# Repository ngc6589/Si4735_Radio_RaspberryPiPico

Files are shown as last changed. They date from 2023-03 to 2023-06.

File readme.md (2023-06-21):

# Si4735ラジオ概要

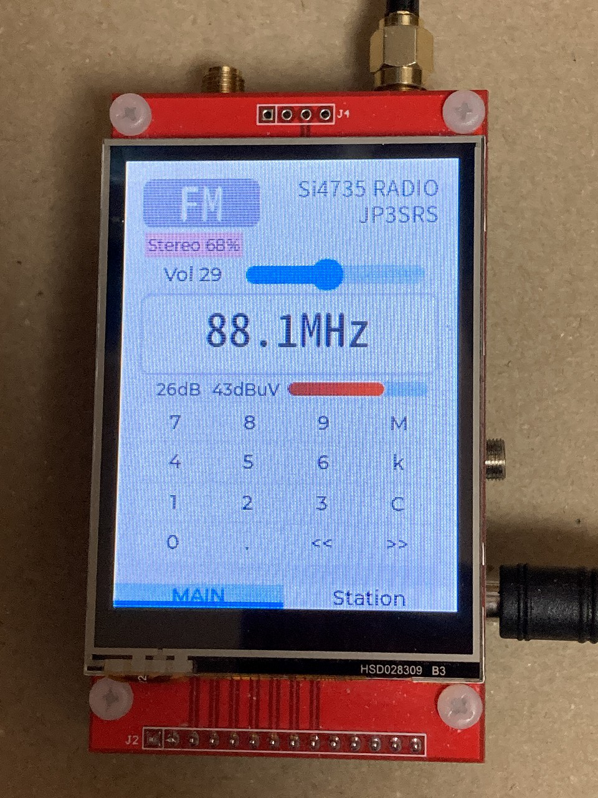
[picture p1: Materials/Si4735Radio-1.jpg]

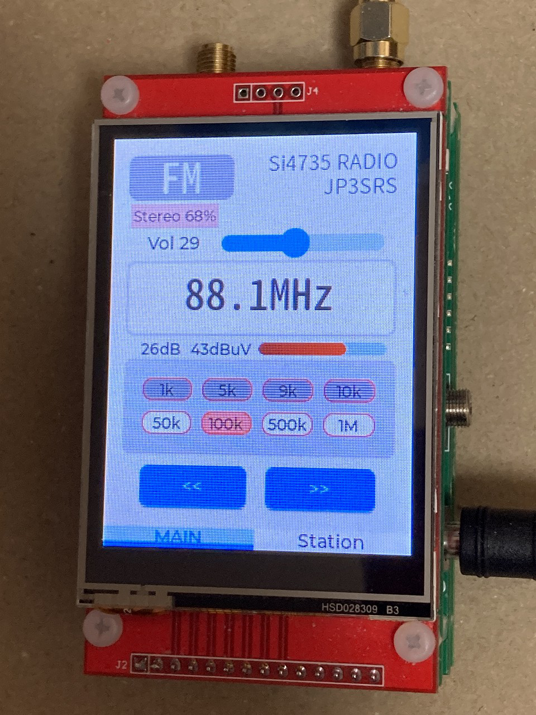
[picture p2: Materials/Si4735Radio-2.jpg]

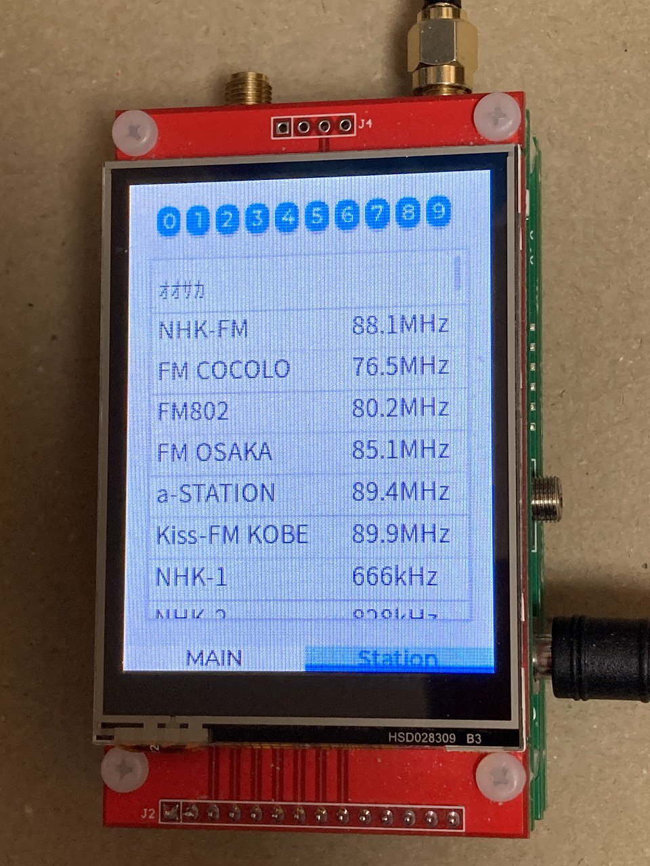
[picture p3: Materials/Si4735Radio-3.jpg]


Raspberry Pi Pico と ILI9341 タッチ液晶を使用し、Si4735 DSP ラジオチップを動かすラジオを製作しました。写真のように周波数を入力してチューニングする画面、ステップ周波数のUP/DOWNチューニング、選局リストからチューニングのモードを備えています。
このラジオの Raspberry Pi Pico のファームウエアは micropython に lvgl グラフィックライブラリをバインドした lv_micropython というものを使用しています。この lv_micropython は https://github.com/lvgl/lv_micropython にて公開されています。これにフリーフォントなどを加えたカスタマイズ版のファームウエアを作成しています。
このファームウエアに micropython で記述したラジオアプリケーションを動かして上記機能を実現しました。

現在 MicroPython は 1.20 がリリースされましたが、lv_micropython はまだ 1.19 なので、当ラジオのファームウエアの MicroPython は 1.19 です。

## 資料

|フォルダ|用途|
|---|---|
|Application|Raspberry Pi Pico の Micro Python ローカルストレージに格納するファイルです|
|Doc|回路図の pdf と部品表のエクセルファイル|
|KiCad_RaspberryPiPico|Raspberry Pi Pico の KiCad ファイルです。ガーバーは pico-20230412 フォルダに入っています|
|KiCad_SP|マイクロスピーカーを着ける KiCad ファイルです。ガーバーは SP-20230412 フォルダに入っています|
|KiCad_Si4735|Si4735 の KiCad ファイルです。ガーバーは RD-20230412 フォルダに入っています。この基板は4層です。
|lv_micropython_Firmware|Raspberry Pi Pico の Flash に書き込む lv_micropython のファームウエアです。firmware.uf2 を書き込んで下さい。

KiCad ファイルはバージョンは 7.0.2 で作成しました。

## 制限事項

* 画面ハングアップ

Raspberry Pi Pico の RAMが 264kB なので画面にグラフィックスウイジェットをたくさん出すとハングアップします。特に選局リストは放送局分のオブジェクトを内部で作成するので、選局リストをいじくりまわしていると固まることが多いです。選局して放置している分には特にハングアップは発生しません。
画面が動かなくなった場合が液晶基板右上に白いタクトスイッチが付いてます。これは RESET スイッチです。これを押して再起動してください。

今後 lvgl や micropython の新バージョンがリリースされても改善の見込みはありません。

* 電源スイッチはありません
* 電源電圧は 5V です。 

Raspberry Pi Pico のUSB端子もしくはとDCジャックから給電します。同時挿しも問題ありません。DCジャックから給電する場合は 5V のスイッチング AC アダプタを使用してください。

トランス式 AC アダプタの場合は表示が 5V でも電源電圧が 5V 以上になっているため使用できません。ラジオのボードは壊れます。

* 放送受信状態は、ご使用になられる場所。アンテナなどの受信設備の違いなど。受信環境の変化要素が多いため一定の保証をすることは困難です。あらかじめご了承願います。

## 簡単な使用方法

### 周波数入力とステップチューニング切り替え

周波数入力選局とステップチューニング画面は、画面上の余白をロングタップすると切り替わります。

### 選局リスト表示

選局リストチューニングは画面をスワイプもしくは画面下部の Station を押すと画面遷移します。戻るときは画面下部の MAIN を押すか画面スワイプで戻ります。

選局リスト画面上部に 0 ～ 9 のボタンがあります。ボタンをクリックすると micropython 内部ファイルシステムに格納してある [0-9].txt のファイルをリードして画面に表示します。

選局したい局の行をクリックするとその放送局にチューニングします。

### 周波数入力チューニング

周波数入力する時は「Ｃ」ボタンを押して、周波数表示が消えた状態で数字を入れて「ｋ」か「Ｍ」ボタンをクリックして選局します。
入力途中で「Ｃ」を押すと元の周波数表示に戻ります。
「＜＜」「＞＞」はシークチューニングです。シーク後放送局が見つかるとシーク動作は停止します。

### ステップチューニング

周波数表示の下に選択可能な周波数ステップボタンが表示されています。画面下部の「<<」「>>」1回クリックすると指定されたステップでチューニングします。長押しで連続ステップチューニング動作をします。

## AMモードゲインボリューム

LW/MW/SW 受信時は SMA コネクタの後に 3SK291 を使用した1石高周波増幅回路を搭載しています。増幅率は左側面アンテナコネクタ近くにボリウムを設けています。このボリウムを回して放送の聞こえ具合を調整してください。左に回し切ると1石増幅器は停止し、放送は聞こえなくなります。右に回し切るとお住まいの電波環境にもよりますが複数の局が混信して聞こえることがあります。

## アンテナ端子について

正面から見て左が LW/MW/SW 用で右が FM 放送用のアンテナ端子です。アンテナ端子の形状は SMA タイプです。

## I2S 出力端子について

2023年6月21日以前に購入された方は、I2S 出力ピンヘッダ横のダンピング抵抗 R1, R2, R3 を 100Ωに変えていただくことでビットクロックなどの波形が安定します。

|端子名|備考|
|-|-|
|BCLK|ビットクロック|
|DATA|データ|
|LRCK|LRクロック|
|GND|グランド|
|NC|未接続|
|VCC|5V出力 3.3vではありません|

I2S 出力するときは、プログラムのラジオチップ初期化のコマンドを I2S 出力対応にする必要があります。

```
# Generate 48k I2S clock
# uncomment I2S OUTPUT
# @rp2.asm_pio(
#     sideset_init=(rp2.PIO.OUT_HIGH, rp2.PIO.OUT_HIGH)
# )
# def gen48k():
#     set(x, 30)       .side(0b00) [1]
#     nop()            .side(0b01) [1]
#     label("L01")
#     nop()            .side(0b00) [1]
#     jmp(x_dec, "L01").side(0b01) [1]
#     set(x, 30)       .side(0b10) [1]
#     nop()            .side(0b11) [1]
#     label("R01")
#     nop()            .side(0b10) [1]
#     jmp(x_dec, "R01").side(0b11) [1]
# 
# sm0 = rp2.StateMachine(
#     0,
#     gen48k,
#     freq=12_288_000,
#     sideset_base=machine.Pin(4)
# )
# sm0.active(1)
```

のコメントを外します。
また、

```
    def FMPOWER_UP(self):
        self.i2c.writeto(self.addr, bytes([0x01, 0x00, 0x05]))  # analog Out
#         self.i2c.writeto(self.addr, bytes([0x01, 0x00, 0xB0]))   # I2S
        self.waitCTS()
        time.sleep(0.5)
        self.setProperty(bytes([0xFF, 0x00, 0x00, 0x00]))          # Turn off Debug Mode
#         self.setProperty(bytes([0x01, 0x04, 0xBB, 0x80]))        # I2s sample rate
```
```
    def AMPOWER_UP(self):
        self.i2c.writeto(self.addr, bytes([0x01, 0x01, 0x05])) # analog out
#         self.i2c.writeto(self.addr, bytes([0x01, 0x01, 0xB0]))  # I2S
        self.waitCTS()
        time.sleep(0.5)
        self.setProperty(bytes([0xFF, 0x00, 0x00, 0x00]))         # Turn off Debug Mode
#         self.setProperty(bytes([0x01, 0x04, 0xBB, 0x80]))       # I2S sample rate
```
の # analog out の行をコメントアウトして i2s のコメントを外すと I2S 出力になります。

デフォルトは 16bit/48k になります。

# プログラム更新

## thonny IDE
今回、ラジオのアプリケーション作成には 
Thonny Python IDE for beginners

https://thonny.org/

で、公開されている IDE を使用しています。
プログラムの修正などしてみる場合はこれをインストールして Si4735Radio の USB 接続すれば lv_micropython の REPL が使えるようになります。

ローカルのファイルを lv_micropython のファイルシステムにコピーしたりその逆も可。ファイルの修正も可能です。

## ファームウエア更新

液晶基板上側両再度に白いタクトスイッチが左右2個付いています。右がリセット・左がBOOTです。

「左BOOT」「右RESET」 両方押す

「右RESET」 離す

「左BOOT」 離す

この後 Raspberry Pi Pico は USB メモリモードになってホスト側PCのファイルに RPI PICO のドライブが使えるようになります。ここに .uf2 ファイルのドラッグ・ドロップ(コピーペースト)すればファームウエアの更新が可能です。

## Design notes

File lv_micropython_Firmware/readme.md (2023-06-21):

|folder|Version |
|---|--- |
|v1.19.1-678-ga71d593c2|lv_MicroPython 1.19.1 |
|v1.20.0-698-g3f25a765d|lv_microPython 1.20.0 |

-gハッシュ番号 は git の短いハッシュ番号です。当ラジオの Raspberry Pi Pico Firmware は、表にあるハッシュ番号がチェックアウトされた状態でビルドされています。

Raspberry Pi Pico の Boot ボタンを押した状態で PC に接続すると、PC に USB ストレージが追加されます。 firmware.uf2 をドラッグ＆ドロップで書き込みを行ってください。

lvgl MicroPython のリポジトリは以下のリンクです。
https://github.com/lvgl/lv_micropython

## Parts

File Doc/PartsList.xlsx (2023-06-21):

■Raspberry Pi Pico board
Reference(s) | Qty | Value | ITEM NUMBER | LINK
U1 | 1 | Raspberry Pi Pico | M-16132 | https://akizukidenshi.com/catalog/g/gM-16132/
LCD1 | 1 | MSP2807_ILI9341_2.8_SPI | M-16265 | https://akizukidenshi.com/catalog/g/gM-16265/
J1 | 1 | Pin Header 2x8 | C-00082 | https://akizukidenshi.com/catalog/g/gC-00082/
J2, J3 **1 | 2 | Pin Header 1x3 R/A
R1, R2 | 2 | 4.7k SMD 0603(1608) | 541-5454-1-ND | https://www.digikey.jp/ja/products/detail/vishay-dale/CRCW06034K70FKEAC/7925175
R3, R4, R5, R6 **3 | 4 | 100 SMD 0603(1608)
R7, R8, R9, R10, R11, R12, R13, R14, R15 | 9 | 51 SMD 0604(1608) | 541-51.0HCT-ND | https://www.digikey.jp/ja/products/detail/vishay-dale/CRCW060351R0FKEA/1174520
C1 **2 | 1 | 0.1uF SMD 0603(1608)
SW1, SW2 | 2 | TACTILE SWITCH | P-14890 | https://akizukidenshi.com/catalog/g/gP-14890/
 |  |  | 679-2400-ND | https://www.digikey.jp/ja/products/detail/apem-inc/MJTP1117/1795496
■Si4735 Board
Reference(s) | Qty | Value
U1 | 1 | Si4735-D60-GU | 336-2140-ND | https://www.digikey.jp/ja/products/detail/skyworks-solutions-inc/SI4735-D60-GU/2674322
U2 | 1 | TPA711DR | 296-1950-1-ND | https://www.digikey.jp/ja/products/detail/texas-instruments/TPA711DR/374589
U3 | 1 | TPA6111A2DR | 296-10846-1-ND | https://www.digikey.jp/ja/products/detail/texas-instruments/TPA6111A2DR/382220
Q1 | 1 | 3SK291 | I-10827 | https://akizukidenshi.com/catalog/g/gI-10827/
C1 | 1 | 100uF/25V SMD 6.3x7.7 | P-14452 | https://akizukidenshi.com/catalog/g/gP-14452/
C2, C12, C16 **2 | 3 | 0.1uF SMD 0603(1608)
C3 | 1 | 0.022uF X7R SMD 0603(1608) | 587-3503-1-ND | https://www.digikey.jp/ja/products/detail/taiyo-yuden/UMK107B7223KAHT/4157349
C4, C6 | 2 | 0.01uF SMD 0603(1608) | P-13387 | https://akizukidenshi.com/catalog/g/gP-13387/
C5 | 1 | 0.47uF X7R SMD 0603(1608) | 587-3170-1-ND | https://www.digikey.jp/ja/products/detail/taiyo-yuden/UMK107B7474KA-TR/3194963
C7 | 1 | 1000pF SMD 0603(1608) | P-02332 | https://akizukidenshi.com/catalog/g/gP-02332/
C10, C13 | 2 | 47uF SMD 1210(3225) | P-16078 | https://akizukidenshi.com/catalog/g/gP-16078/
C11, C15, C23 | 3 | 10p SMD 0603(1608) | P-05520 | https://akizukidenshi.com/catalog/g/gP-05520/
C14, C18, C20, C22 | 4 | 1uF X7R SMD 0603(1608) | P-14526 | https://akizukidenshi.com/catalog/g/gP-14526/
C17, C21 | 2 | 330uF/6.3V D=8mm PITCH=2.5mm | P-08374 | https://akizukidenshi.com/catalog/g/gP-08374/
C19 | 1 | 2.2uF SMD 0603(1608) | P-16077 | https://akizukidenshi.com/catalog/g/gP-16077/
D1 | 1 | 1N5819HW SOD-123 | 1N5819HW-FDICT-ND | https://www.digikey.jp/ja/products/detail/diodes-incorporated/1N5819HW-7-F/814970
D2, D3, D4, D5, D6, D7 | 6 | 1N4148W SOD-123 | I-07084 | https://akizukidenshi.com/catalog/g/gI-07084/
EMI1, EMI2, EMI3, EMI4, EMI5 | 5 | 4.7uF/6.3V FEEDTHRU 0603(1608) | 445-7080-1-ND | https://www.digikey.jp/ja/products/detail/tdk-corporation/YFF18PC0J475MT0H0N/2674882
J1 **1 | 1 | Pin Header 1x6 R/A
J2 | 1 | DC JACK MJ-179P | C-00077 | https://akizukidenshi.com/catalog/g/gC-00077/
J3 | 1 | Pin Socket 2x8 | C-02761 | https://akizukidenshi.com/catalog/g/gC-02761/
J4, J5 | 2 | AM/SW, FM | C-13195 | https://akizukidenshi.com/catalog/g/gC-13195/
J6 | 1 | MJ-352W-C | C-17359 | https://akizukidenshi.com/catalog/g/gC-17359/
L1 | 1 | FT37-77 (5977000201) 12T | 1934-1032-ND | https://www.digikey.jp/ja/products/detail/fair-rite-products-corp/5977000201/8593966
R1, R2, R3 **3 | 2 | 100 SMD 0603(1608)
R4 | 1 | 10 SMD 0603(1608) | 541-3952-1-ND | https://www.digikey.jp/ja/products/detail/vishay-dale/CRCW060310R0FKEAC/7928374
R5 | 1 | 22k SMD 0603(1608) | 541-4036-1-ND | https://www.digikey.jp/ja/products/detail/vishay-dale/CRCW060322K0FKEAC/7928458
R6 | 1 | 91k SMD 0603(1608) | 541-5595-1-ND | https://www.digikey.jp/ja/products/detail/vishay-dale/CRCW060391K0FKEAC/7924350
R7 | 1 | 39k SMD 0603(1608) | 541-5383-1-ND | https://www.digikey.jp/ja/products/detail/vishay-dale/CRCW060339K0FKEAC/7924024
R8, R16, R17 | 3 | 100k SMD 0603(1608) | 541-3950-1-ND | https://www.digikey.jp/ja/products/detail/vishay-dale/CRCW0603100KFKEAC/7928372
R9 | 1 | 47k SMD 0603(1608) | 541-4021-1-ND | https://www.digikey.jp/ja/products/detail/vishay-dale/CRCW060347K0FKEAC/7928443
R10, R14, R15, R19, R20 | 5 | 10k SMD 0603(1608) | 541-5136-1-ND | https://www.digikey.jp/ja/products/detail/vishay-dale/CRCW060310K0FKEAC/7924693
R11, R18 | 2 | 33k SMD 0603(1608) | 541-4041-1-ND | https://www.digikey.jp/ja/products/detail/vishay-dale/CRCW060333K0FKEAC/7928463
R12, R13 | 2 | 1k SMD 0603(1608) | 541-3949-1-ND | https://www.digikey.jp/ja/products/detail/vishay-dale/CRCW06031K00FKEAC/7928371
RV1 | 1 | 10k | P-14937 | https://akizukidenshi.com/catalog/g/gP-14937/
 |  |  | 312-1001F-10K | https://www.mouser.jp/ProductDetail/Alpha-Taiwan/RV100F-30-4K1B-B10K-B301?qs=e7hy8iQCIdxa76GAgn%252BWaA%3D%3D
RV2 | 1 | 10k TRIMMER | 3306W-103-ND | https://www.digikey.jp/ja/products/detail/bourns-inc/3306W-1-103/84781
LS1 **1 | 1 | 1x2 Pin Header
LS1 | 1 | MICRO SPEAKER | P-12495 | https://akizukidenshi.com/catalog/g/gP-12495/
■Si4735 Crystal Option
Reference(s) | Qty | Value
Y1 | 1 | 32.768kHz 3.2×1.5×0.80mm | P-07195 | https://akizukidenshi.com/catalog/g/gP-07195/
C8, C9 | 2 | 12pF C0G SMD 0603(1608) | 399-CBR06C120J5GACCT-ND | https://www.digikey.jp/ja/products/detail/kemet/CBR06C120J5GAC/3473711
■screw / other
Reference(s) | Qty | Value
M3 Screw 4mm | 8 | plastic screws M3 Length 4mm | N-0304 | https://www.hirosugi-net.co.jp/shop/g/g35880/
M3 Spacer 6mm | 8 | Duracon spacer M3 Length 6mm | BS-306E | https://www.hirosugi-net.co.jp/shop/g/g3761/
M3 Spacer 11mm | 4 | Duracon spacer M3 Length 11mm internal thread | AS-311 | https://www.hirosugi-net.co.jp/shop/g/g3724/
0.4 - 0.5mm UEW Wire | 1 | use L1 (FT37-77) 12T
**1
Pin Header 1x40 R/A | 1 | Pin Head 1x40 R/A | C-01627 | https://akizukidenshi.com/catalog/g/gC-01627/
**2
0.1uF (100n) | 3 | 0.1uF SMD 0603(1608) | P-16143 | https://akizukidenshi.com/catalog/g/gP-16143/
**3
100 ohm | 7 | 100 SMD 0603(1608) | 541-3951-1-ND | https://www.digikey.jp/ja/products/detail/vishay-dale/CRCW0603100RFKEAC/7928373

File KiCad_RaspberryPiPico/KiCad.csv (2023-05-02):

Source: | C:\Users\masahiro\OneDrive\make\_K-0025_Si4735Radio\KiCad_RaspberryPiPico\KiCad.kicad_sch
Date: | 2023/04/29 8:51:12
Tool: | Eeschema 7.0.2
Generator: | C:\Program Files\KiCad\7.0\bin\scripting\plugins/bom_csv_grouped_by_value.py
Component Count: | 27
Collated Components:
Item | Qty | Reference(s) | Value | LibPart | Footprint | Datasheet | DNP
1 | 1 | C1 | 0.1uF | Device:C | Capacitor_SMD:C_0603_1608Metric_Pad1.08x0.95mm_HandSolder | ~
2 | 4 | H1, H2, H3, H4 | MountingHole | Mechanical:MountingHole | MountingHole:MountingHole_3.2mm_M3 | ~
3 | 1 | J1 | Conn_02x08_Odd_Even | Connector_Generic:Conn_02x08_Odd_Even | Connector_PinHeader_2.54mm:PinHeader_2x08_P2.54mm_Vertical | ~
4 | 1 | J2 | DEBUG | Connector:Conn_01x03_Socket | Connector_PinSocket_2.54mm:PinSocket_1x03_P2.54mm_Horizontal | ~
5 | 1 | J3 | UART | Connector:Conn_01x03_Socket | Connector_PinSocket_2.54mm:PinSocket_1x03_P2.54mm_Horizontal | ~
6 | 1 | LCD1 | MSP2807_ILI9341_2.8_SPI | _localSymbol:MSP2807_ILI9341_2.8_SPI_wo_SD | Connector_PinSocket_2.54mm:PinSocket_1x14_P2.54mm_Vertical
7 | 2 | R1, R2 | 4.7k | Device:R | Resistor_SMD:R_0603_1608Metric_Pad0.98x0.95mm_HandSolder | ~
8 | 4 | R3, R4, R5, R6 | 100 | Device:R | Resistor_SMD:R_0603_1608Metric_Pad0.98x0.95mm_HandSolder | ~
9 | 9 | R7, R8, R9, R10, R11, R12, R13, R14, R15 | 51 | Device:R | Resistor_SMD:R_0603_1608Metric_Pad0.98x0.95mm_HandSolder | ~
10 | 1 | SW1 | RESET | _localSymbol:THBP07-043CW | _localFootprint:THBP07-043CW | http://www.apem.com/int/index.php?controller=attachment&id_attachment=1371
11 | 1 | SW2 | BOOT | _localSymbol:THBP07-043CW | _localFootprint:THBP07-043CW | http://www.apem.com/int/index.php?controller=attachment&id_attachment=1371
12 | 1 | U1 | Pico | _localSymbol:Pico | _localFootprint:RPi_Pico_SMD_TH

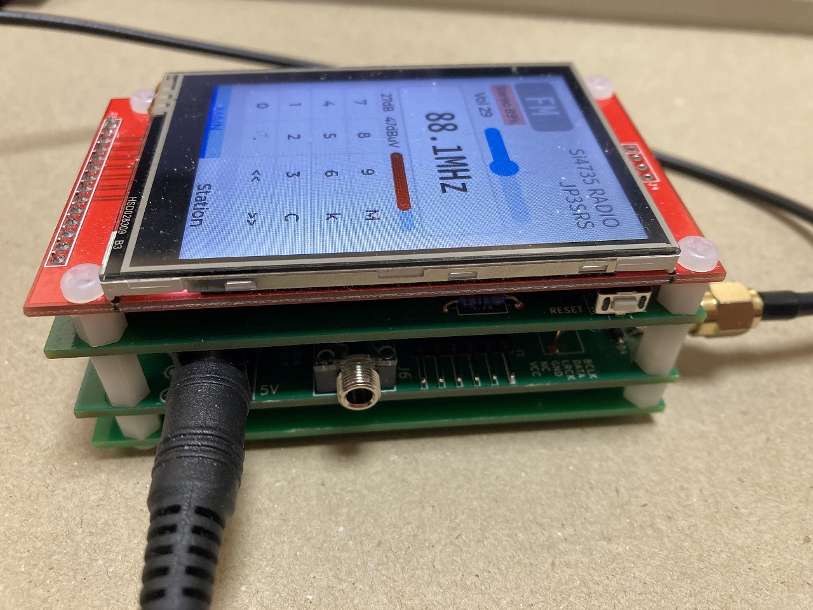
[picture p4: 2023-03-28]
Materials/Si4735Radio-5.jpg

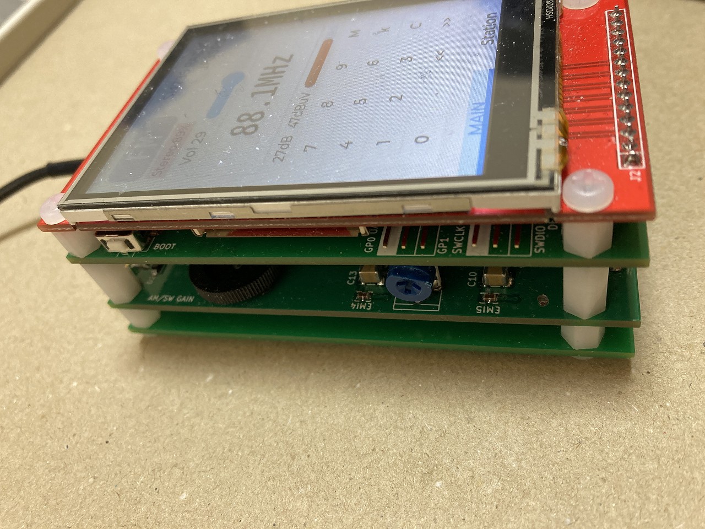
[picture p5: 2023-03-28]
Materials/Si4735Radio-4.jpg

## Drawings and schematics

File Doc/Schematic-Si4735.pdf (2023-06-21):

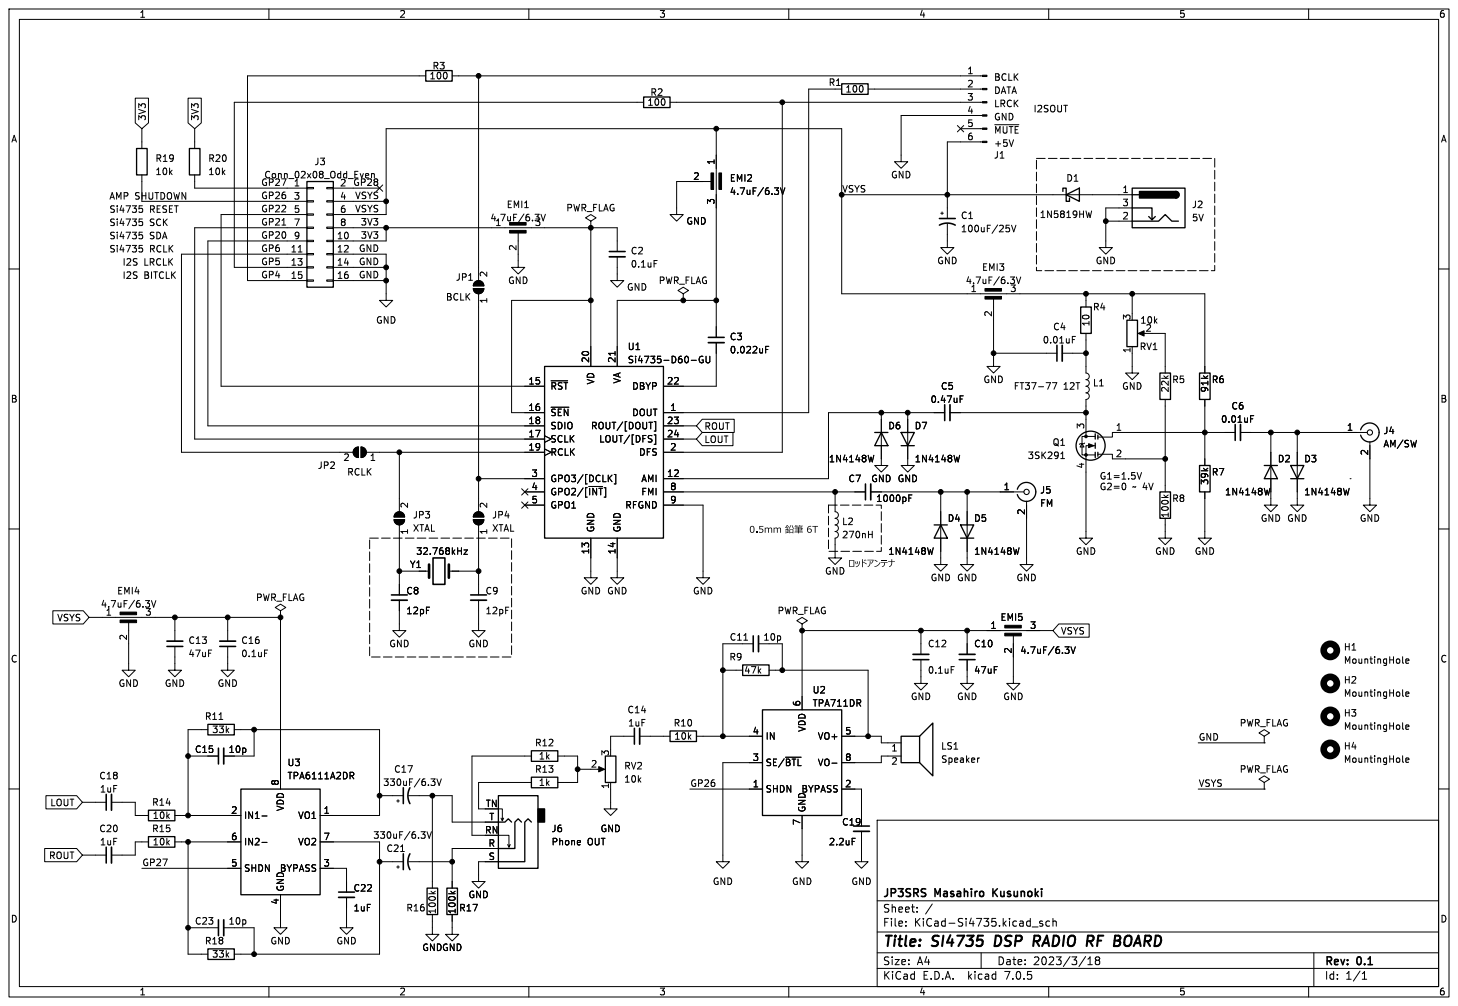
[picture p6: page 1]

1 2 JP4 XTAL DOUT 1 AMI 12 GND 13 GND 14

Id: 1/1 Title: SI4735 DSP RADIO RF BOARD

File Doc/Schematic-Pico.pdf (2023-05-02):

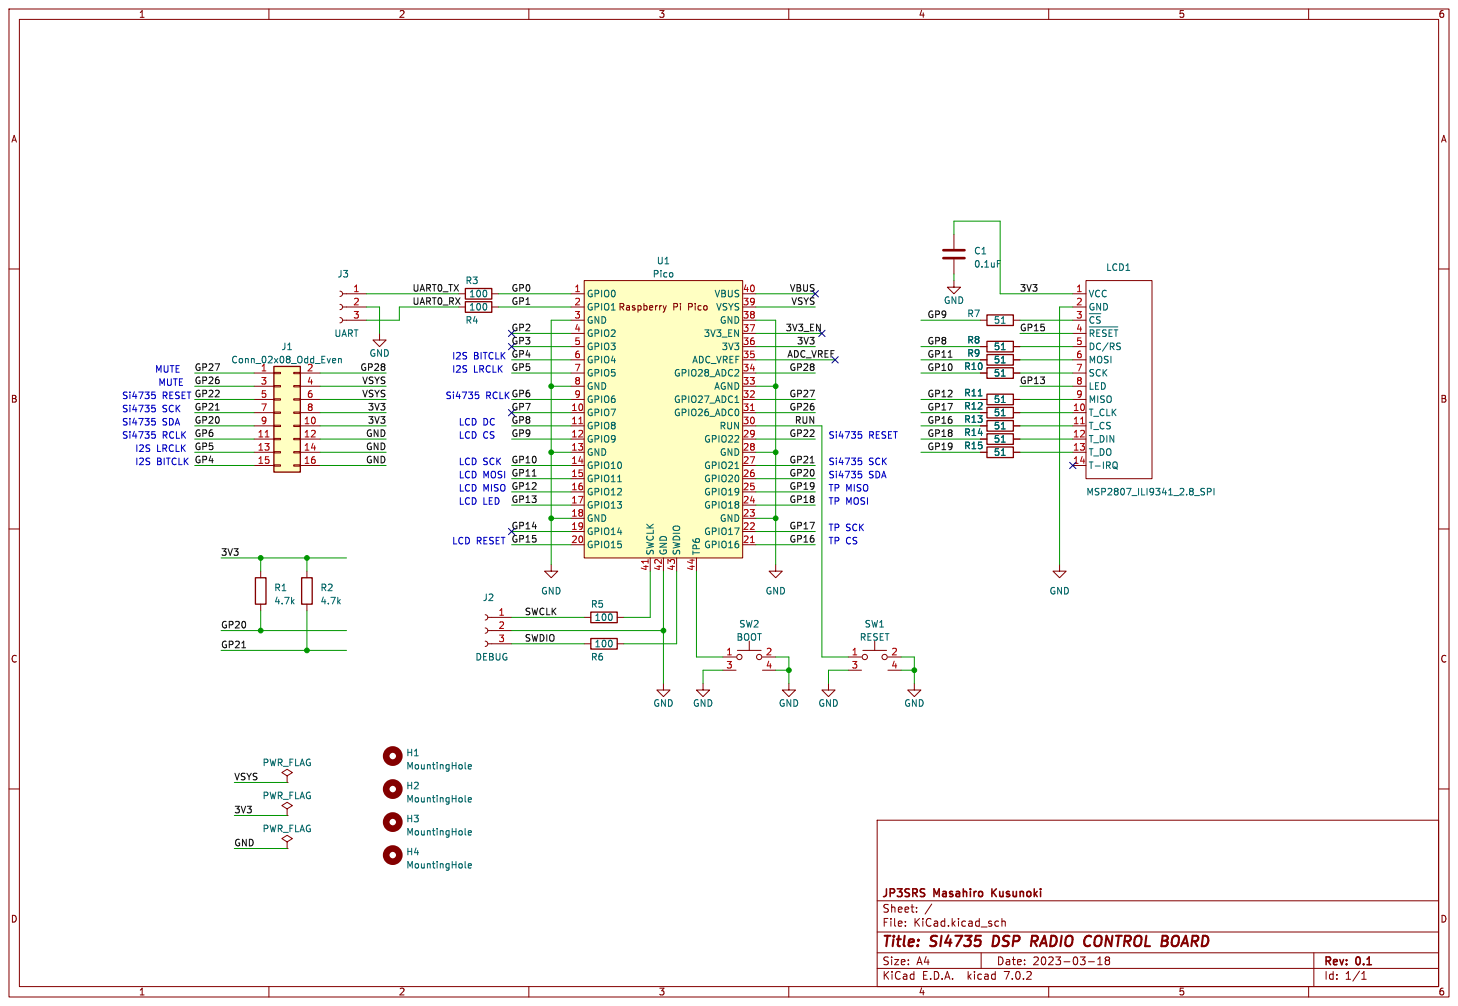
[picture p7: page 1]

LCD MOSI LCD SCK MUTE

Si4735 SCK
Si4735 SDA
TP MISO
TP MOSI TP SCK

H3 MountingHole H2 MountingHole H1 MountingHole H4 MountingHole R1

Id: 1/1 Title: SI4735 DSP RADIO CONTROL BOARD

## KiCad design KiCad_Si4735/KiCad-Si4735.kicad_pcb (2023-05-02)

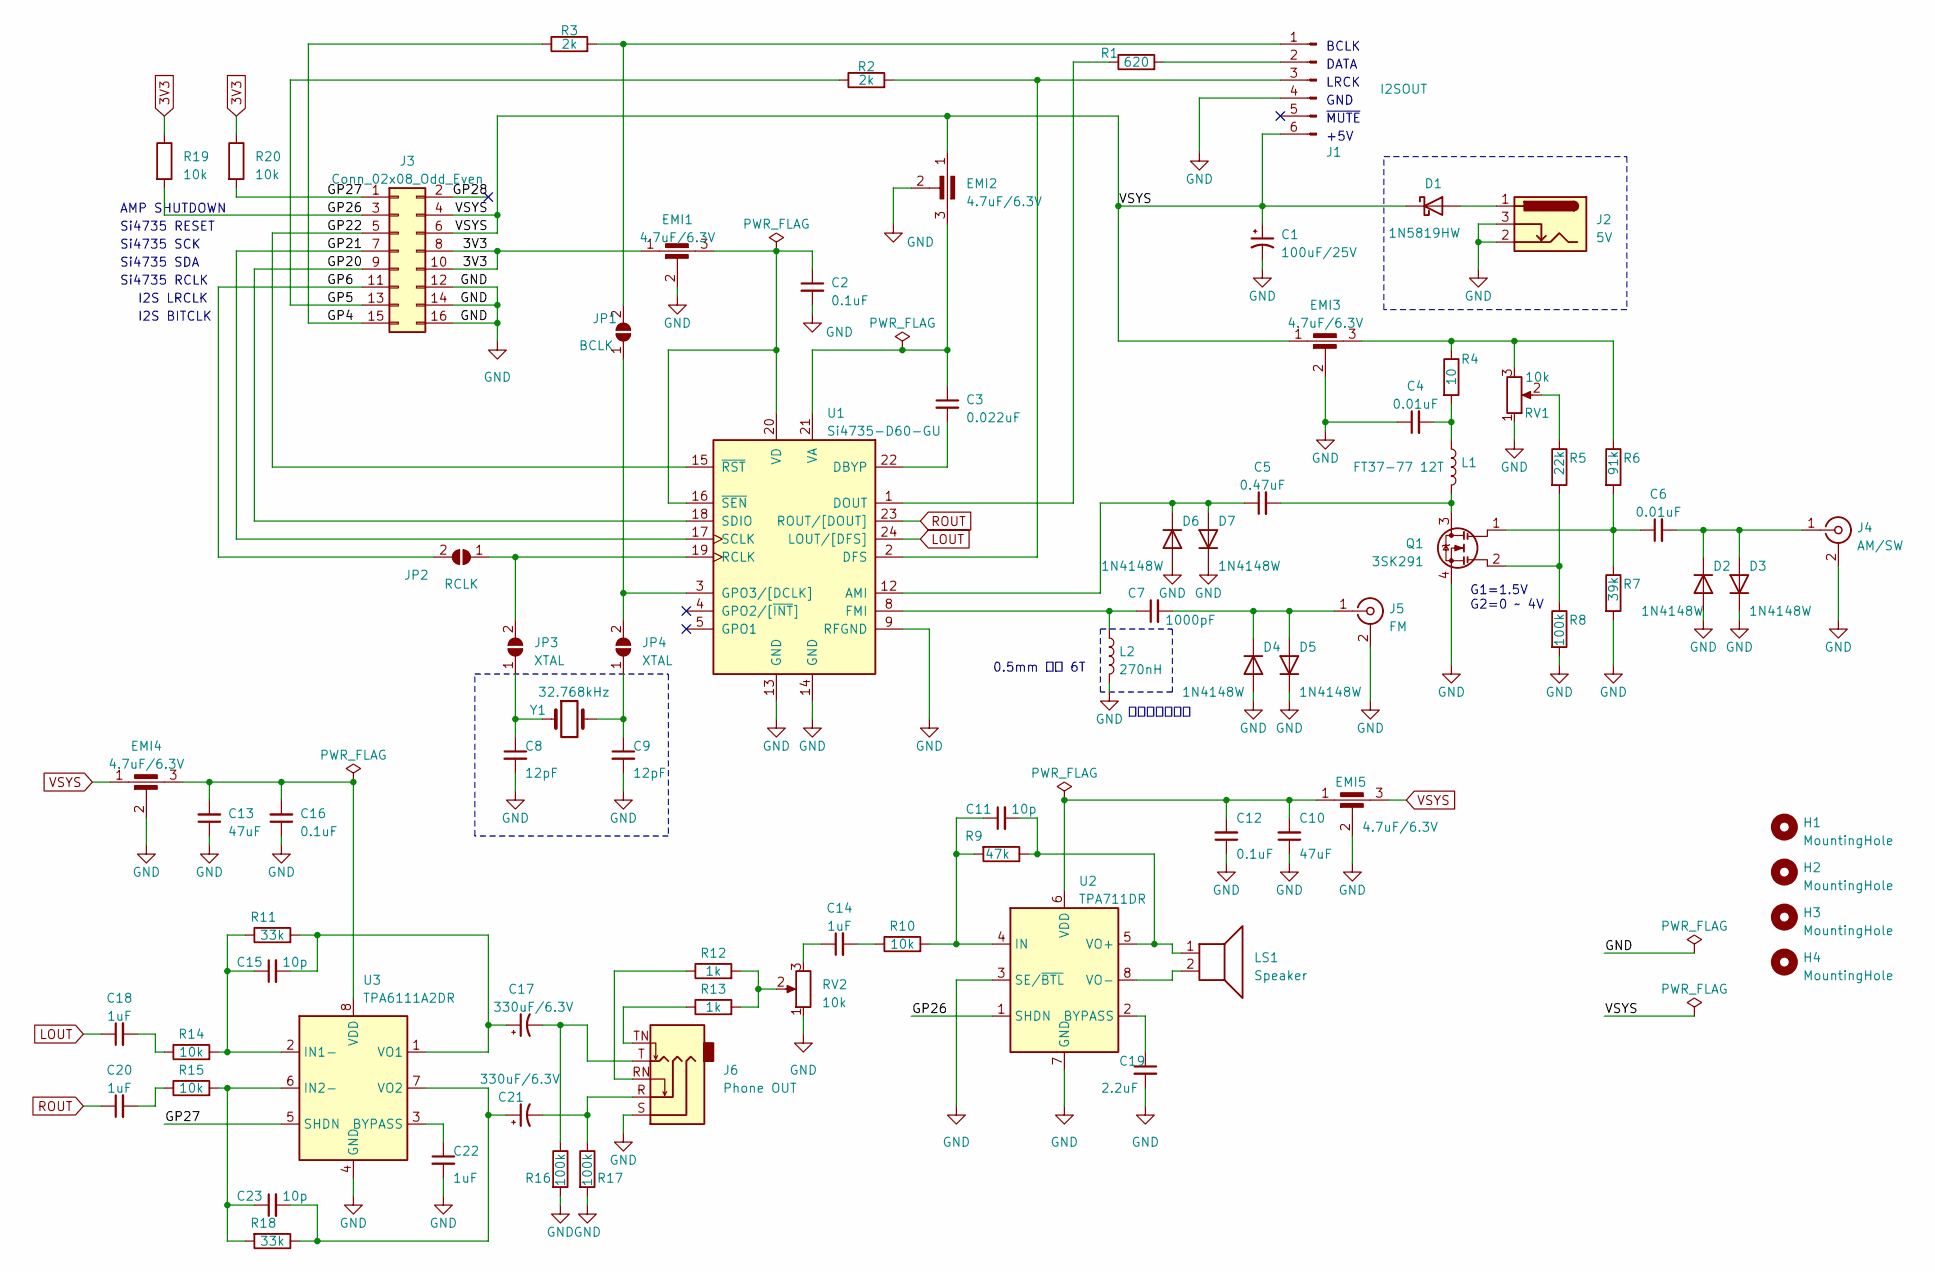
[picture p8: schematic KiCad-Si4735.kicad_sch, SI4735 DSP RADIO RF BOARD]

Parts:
C1: 100uF/25V; CP_Elec_6.3x7.7
C2, C12, C16: 0.1uF; C_0603_1608Metric_Pad1.08x0.95mm_HandSolder
C3: 0.022uF; C_0603_1608Metric_Pad1.08x0.95mm_HandSolder
C4, C6: 0.01uF; C_0603_1608Metric_Pad1.08x0.95mm_HandSolder
C5: 0.47uF; C_0603_1608Metric_Pad1.08x0.95mm_HandSolder
C7: 1000pF; C_0603_1608Metric_Pad1.08x0.95mm_HandSolder
C8, C9: 12pF; C_0603_1608Metric_Pad1.08x0.95mm_HandSolder
C10, C13: 47uF; C_1210_3225Metric_Pad1.33x2.70mm_HandSolder
C11, C15, C23: 10p; C_0603_1608Metric_Pad1.08x0.95mm_HandSolder
C14, C18, C20, C22: 1uF; C_0603_1608Metric_Pad1.08x0.95mm_HandSolder
C17, C21: 330uF/6.3V; CP_Radial_D8.0mm_P2.50mm
C19: 2.2uF; C_0603_1608Metric_Pad1.08x0.95mm_HandSolder
D1: 1N5819HW; D_SOD-123
D2, D3, D4, D5, D6, D7: 1N4148W; D_SOD-123
EMI1, EMI2, EMI3, EMI4, EMI5: 4.7uF/6.3V; YFF18PC
H1, H2, H3, H4: MountingHole; MountingHole_3.2mm_M3
J1: I2SOUT; PinHeader_1x06_P2.54mm_Horizontal
J2: 5V; MJ-179PH
J3: Conn_02x08_Odd_Even; PinHeader_2x08_P2.54mm_Vertical
J4: AM/SW; SMA-J-P-H-ST-EM1
J5: FM; SMA-J-P-H-ST-EM1
J6: Phone OUT; MJ-352W-0
JP1: BCLK; SolderJumper-2_P1.3mm_Open_Pad1.0x1.5mm
JP2: RCLK; SolderJumper-2_P1.3mm_Open_Pad1.0x1.5mm
JP3, JP4: XTAL; SolderJumper-2_P1.3mm_Open_Pad1.0x1.5mm
L1: FT37-77 12T; FT37
L2: 270nH; L2
LS1: Speaker; PinHeader_1x02_P2.54mm_Horizontal
Q1: 3SK291; SOT-143_Handsoldering
R1: 620; R_0603_1608Metric_Pad0.98x0.95mm_HandSolder
R2, R3: 2k; R_0603_1608Metric_Pad0.98x0.95mm_HandSolder
R4: 10; R_0603_1608Metric_Pad0.98x0.95mm_HandSolder
R5: 22k; R_0603_1608Metric_Pad0.98x0.95mm_HandSolder
R6: 91k; R_0603_1608Metric_Pad0.98x0.95mm_HandSolder
R7: 39k; R_0603_1608Metric_Pad0.98x0.95mm_HandSolder
R8, R16, R17: 100k; R_0603_1608Metric_Pad0.98x0.95mm_HandSolder
R9: 47k; R_0603_1608Metric_Pad0.98x0.95mm_HandSolder
R10, R14, R15, R19, R20: 10k; R_0603_1608Metric_Pad0.98x0.95mm_HandSolder
R11, R18: 33k; R_0603_1608Metric_Pad0.98x0.95mm_HandSolder
R12, R13: 1k; R_0603_1608Metric_Pad0.98x0.95mm_HandSolder
RV1: 10k; RV100F
RV2: 10k; 3306W
U1: Si4735-D60-GU; SSOP-24_3.9x8.7mm_P0.635mm
U2: TPA711DR; SO-8_3.9x4.9mm_P1.27mm
U3: TPA6111A2DR; SO-8_3.9x4.9mm_P1.27mm
Y1: 32.768kHz; FC-135

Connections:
3V3: EMI1.1, J3.8, J3.10, R19.1, R20.1
/GP4: J3.15, R3.1
/GP5: J3.13, R2.1
/GP6: J3.11, JP2.2 (B)
/GP20: J3.9, U1.18 (SDIO)
/GP21: J3.7, U1.17 (SCLK)
/GP22: J3.5, U1.15 (~RST)
/GP26: J3.3, R19.2, U2.1 (SHDN)
/GP27: J3.1, R20.2, U3.5 (SHDN)
/GP28: J3.2
GND: C1.2, C2.2, C4.1, C8.2, C9.2, C10.1, C12.1, C13.1, C16.1, C19.2, C22.2, D2.2 (A), D3.1 (K), D4.2 (A), D5.1 (K), D6.2 (A), D7.1 (K), EMI1.2, EMI2.2, EMI3.2, EMI4.2, EMI5.2, J1.4, J2.2, J2.3, J3.12, J3.14, J3.16, J4.2 (Ext), J5.2 (Ext), J6.S, L2.2, Q1.4 (S), R7.2, R8.2, R16.2, R17.2, RV1.1, RV2.1, U1.9 (RFGND), U1.13 (GND), U1.14 (GND), U2.3 (SE/~BTL), U2.7 (GND), U3.4 (GND)
LOUT: C18.1, U1.24 (LOUT/[DFS])
unnamed: C4.2, L1.1, R4.2
unnamed: C14.1, RV2.3
unnamed: C14.2, R10.1
unnamed: C17.2, J6.T, R16.1
unnamed: C18.2, R14.1
unnamed: C20.2, R15.1
unnamed: C21.2, J6.R, R17.1
unnamed: D1.2 (A), J2.1
unnamed: C6.2, D2.1 (K), D3.2 (A), J4.1 (In)
unnamed: C7.2, D4.1 (K), D5.2 (A), J5.1 (In)
unnamed: C5.1, D6.1 (K), D7.2 (A), U1.12 (AMI)
unnamed: EMI3.3, R4.1, R6.1, RV1.3
unnamed: J1.1, JP1.2 (B), R3.2
unnamed: J1.2, R1.2
unnamed: J1.3, R2.2, U1.2 (DFS)
unnamed: J6.RN, R12.1
unnamed: J6.TN, R13.1
unnamed: JP1.1 (A), JP4.2 (B), U1.3 (GPO3/[DCLK])
unnamed: JP2.1 (A), JP3.2 (B), U1.19 (RCLK)
unnamed: C8.1, JP3.1 (A), Y1.1
unnamed: C9.1, JP4.1 (A), Y1.2
unnamed: C5.2, L1.2, Q1.3 (D)
unnamed: C6.1, Q1.1 (G1), R6.2, R7.1
unnamed: Q1.2 (G2), R5.2, R8.1
unnamed: R5.1, RV1.2
unnamed: R12.2, R13.2, RV2.2
unnamed: C3.2, U1.22 (DBYP)
unnamed: R1.1, U1.1 (DOUT)
unnamed: C7.1, L2.1, U1.8 (FMI)
unnamed: C3.1, EMI2.3, U1.21 (VA)
unnamed: C2.1, EMI1.3, U1.16 (~SEN), U1.20 (VD)
unnamed: C19.1, U2.2 (BYPASS)
unnamed: C11.1, R9.2, R10.2, U2.4 (IN)
unnamed: C10.2, C12.2, EMI5.1, U2.6 (VDD)
unnamed: C11.2, LS1.1, R9.1, U2.5 (VO+)
unnamed: LS1.2, U2.8 (VO-)
unnamed: C22.1, U3.3 (BYPASS)
unnamed: C15.1, R11.1, R14.2, U3.2 (IN1-)
unnamed: C23.1, R15.2, R18.2, U3.6 (IN2-)
unnamed: C13.2, C16.2, EMI4.3, U3.8 (VDD)
unnamed: C15.2, C17.1, R11.2, U3.1 (VO1)
unnamed: C21.1, C23.2, R18.1, U3.7 (VO2)
ROUT: C20.1, U1.23 (ROUT/[DOUT])
VSYS: C1.1, D1.1 (K), EMI2.1, EMI3.1, EMI4.1, EMI5.3, J1.6, J3.4, J3.6

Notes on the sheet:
G1=1.5V G2=0 ~ 4V
LRCK
GND
Si4735 RESET
ロッドアンテナ
DATA
I2S BITCLK
+5V
Si4735 SCK
Si4735 RCLK
~{MUTE}
BCLK
0.5mm 鉛筆 6T
Si4735 SDA
AMP SHUTDOWN
I2S LRCLK

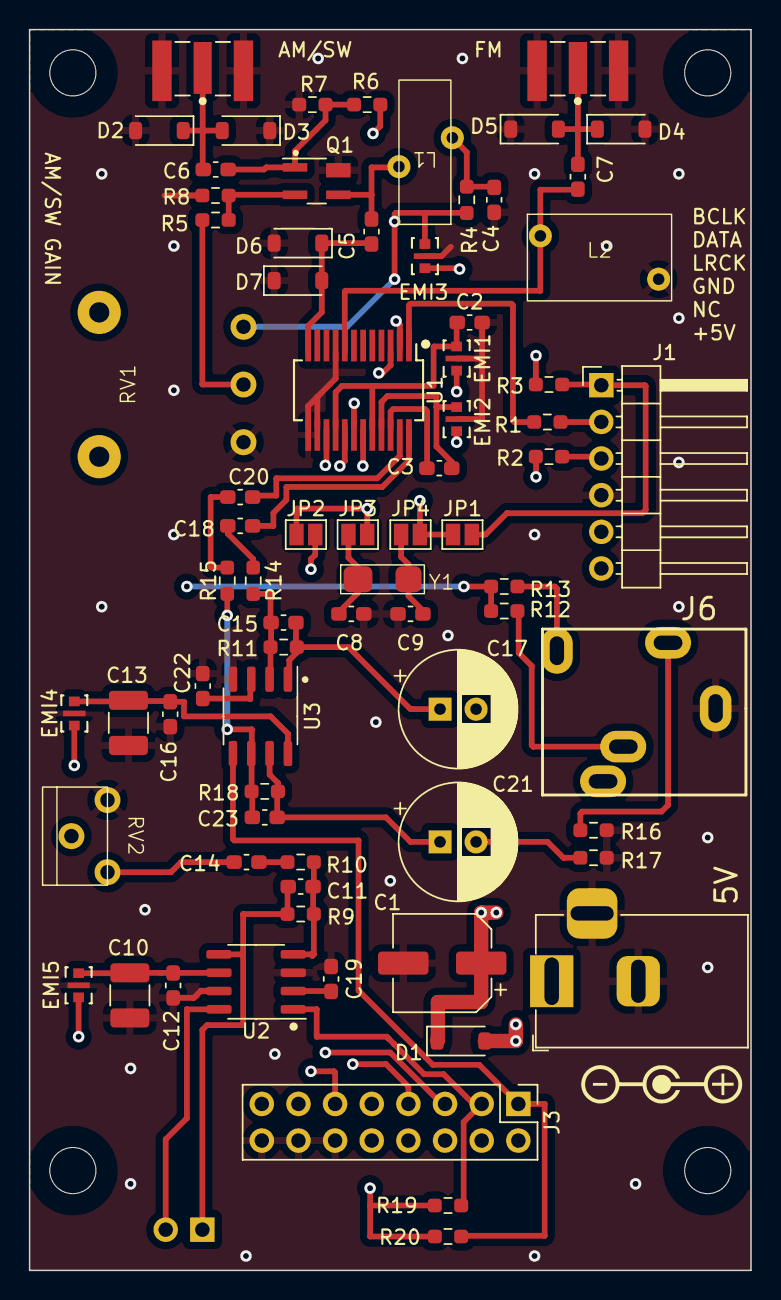
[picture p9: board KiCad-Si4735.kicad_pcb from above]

Board: 4 copper layers, 50.0 x 86.0 mm, 79 parts (1 on the bottom side), 55 nets.

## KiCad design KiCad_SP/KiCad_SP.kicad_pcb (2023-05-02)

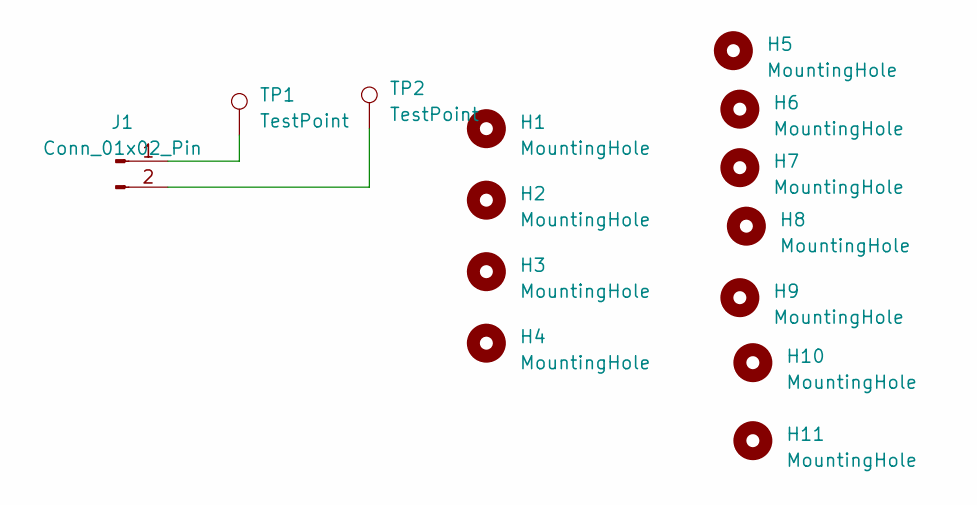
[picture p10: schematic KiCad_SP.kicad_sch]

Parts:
H1, H2, H3, H4: MountingHole; MountingHole_3.2mm_M3
H5, H6, H7, H8, H9, H10, H11: MountingHole; MountingHole_2.5mm
J1: Conn_01x02_Pin; PinHeader_1x02_P2.54mm_Horizontal
TP1, TP2: TestPoint; TestPoint_THTPad_1.0x1.0mm_Drill0.5mm

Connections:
unnamed: J1.1, TP1.1
unnamed: J1.2, TP2.1

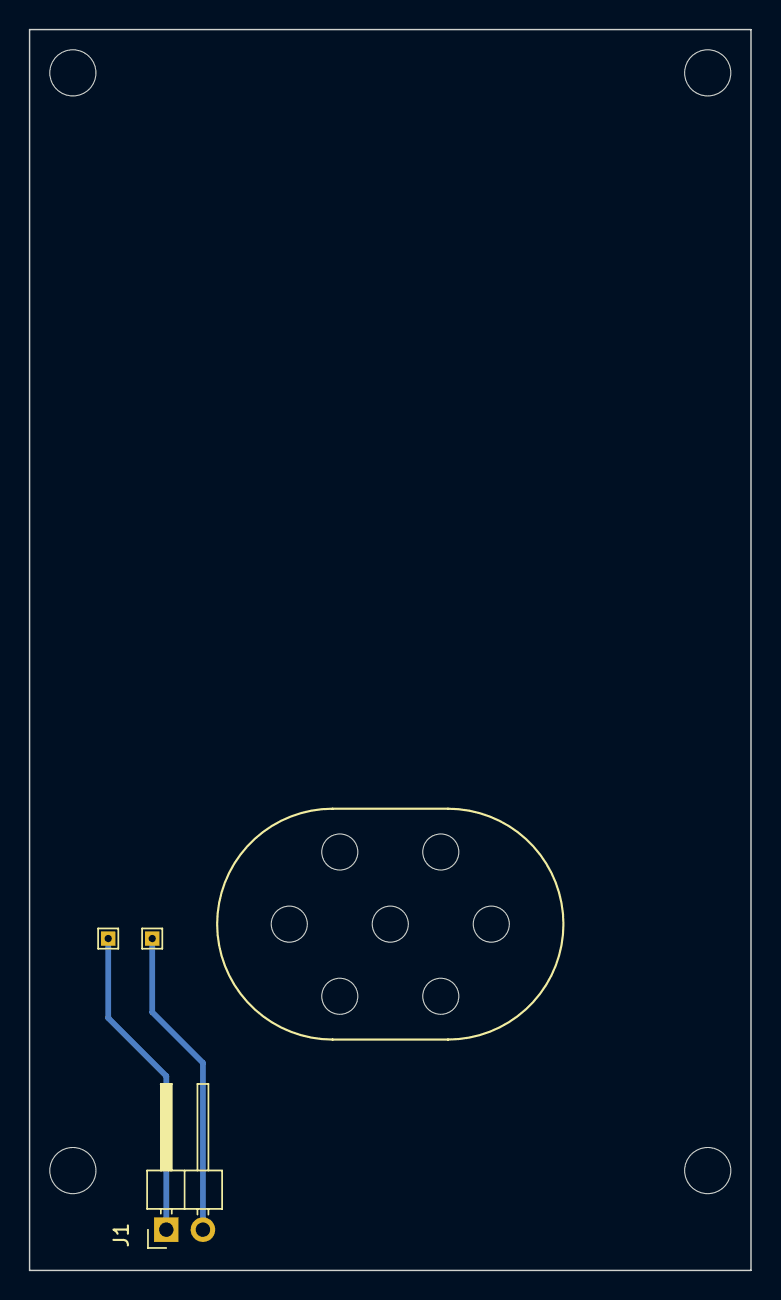
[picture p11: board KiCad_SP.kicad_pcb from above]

Board: 2 copper layers, 50.0 x 86.0 mm, 14 parts (0 on the bottom side), 2 nets.

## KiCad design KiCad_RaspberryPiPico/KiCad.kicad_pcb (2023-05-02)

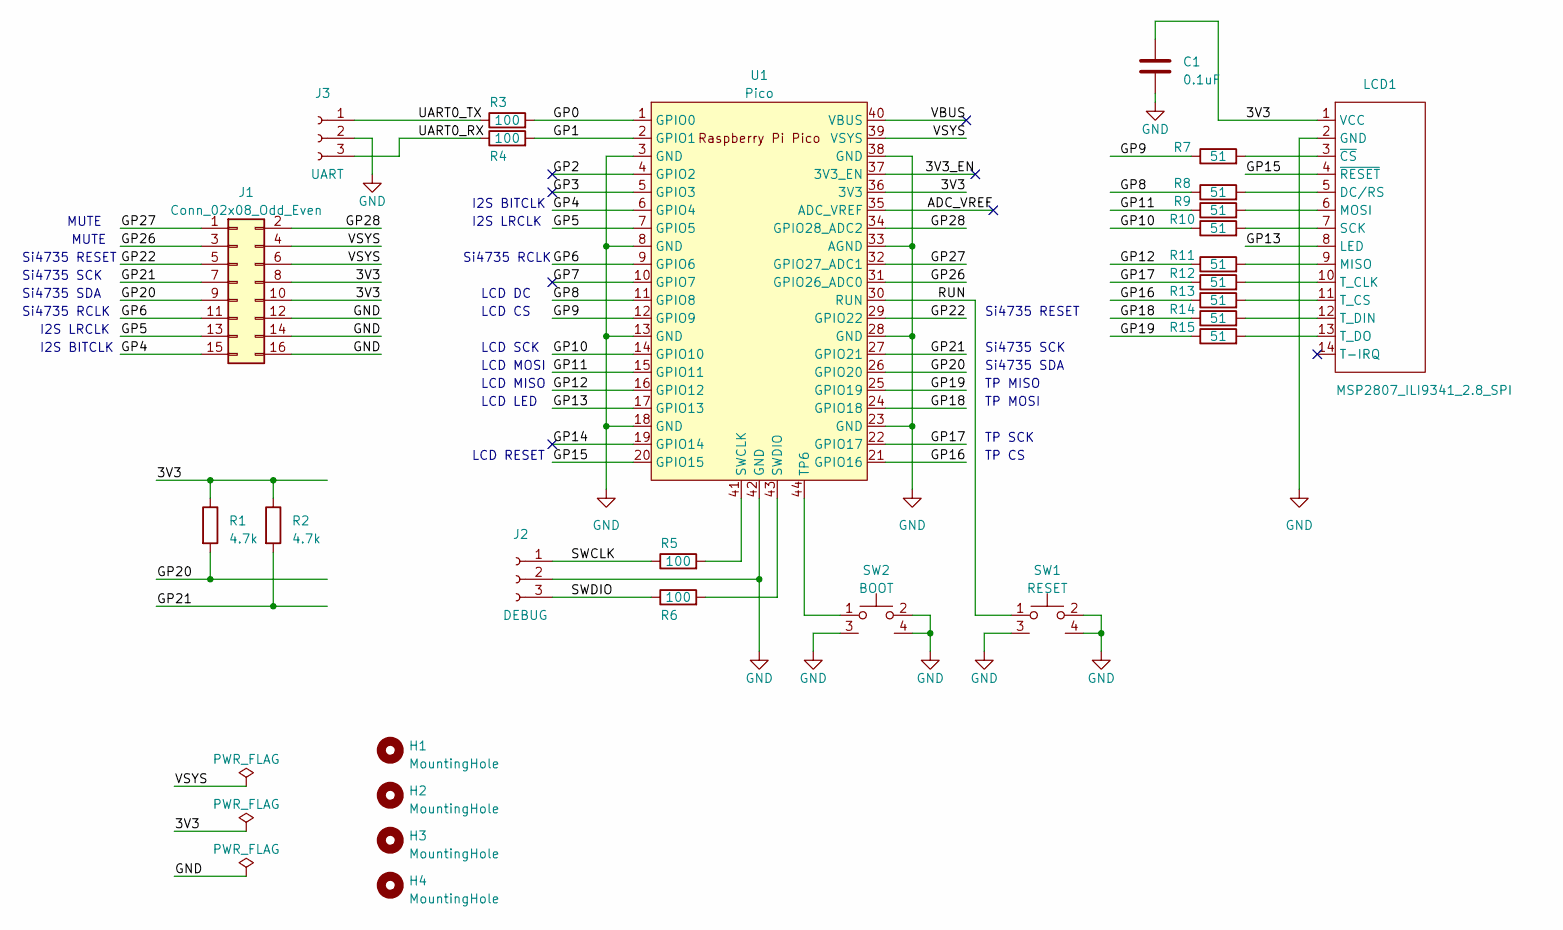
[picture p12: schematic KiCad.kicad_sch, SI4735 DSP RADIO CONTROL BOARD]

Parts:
C1: 0.1uF; C_0603_1608Metric_Pad1.08x0.95mm_HandSolder
H1, H2, H3, H4: MountingHole; MountingHole_3.2mm_M3
J1: Conn_02x08_Odd_Even; PinHeader_2x08_P2.54mm_Vertical
J2: DEBUG; PinSocket_1x03_P2.54mm_Horizontal
J3: UART; PinSocket_1x03_P2.54mm_Horizontal
LCD1: MSP2807_ILI9341_2.8_SPI; PinSocket_1x14_P2.54mm_Vertical
R1, R2: 4.7k; R_0603_1608Metric_Pad0.98x0.95mm_HandSolder
R3, R4, R5, R6: 100; R_0603_1608Metric_Pad0.98x0.95mm_HandSolder
R7, R8, R9, R10, R11, R12, R13, R14, R15: 51; R_0603_1608Metric_Pad0.98x0.95mm_HandSolder
SW1: RESET; THBP07-043CW
SW2: BOOT; THBP07-043CW
U1: Pico; RPi_Pico_SMD_TH

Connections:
/3V3: C1.1, J1.8, J1.10, LCD1.1 (VCC), R1.1, R2.1, U1.36 (3V3)
/3V3_EN: U1.37 (3V3_EN)
/ADC_VREF: U1.35 (ADC_VREF)
/GP0: R3.2, U1.1 (GPIO0)
/GP1: R4.2, U1.2 (GPIO1)
/GP2: U1.4 (GPIO2)
/GP3: U1.5 (GPIO3)
/GP4: J1.15, U1.6 (GPIO4)
/GP5: J1.13, U1.7 (GPIO5)
/GP6: J1.11, U1.9 (GPIO6)
/GP7: U1.10 (GPIO7)
/GP8: R8.1, U1.11 (GPIO8)
/GP9: R7.1, U1.12 (GPIO9)
/GP10: R10.1, U1.14 (GPIO10)
/GP11: R9.1, U1.15 (GPIO11)
/GP12: R11.1, U1.16 (GPIO12)
/GP13: LCD1.8 (LED), U1.17 (GPIO13)
/GP14: U1.19 (GPIO14)
/GP15: LCD1.4 (~RESET), U1.20 (GPIO15)
/GP16: R13.1, U1.21 (GPIO16)
/GP17: R12.1, U1.22 (GPIO17)
/GP18: R14.1, U1.24 (GPIO18)
/GP19: R15.1, U1.25 (GPIO19)
/GP20: J1.9, R1.2, U1.26 (GPIO20)
/GP21: J1.7, R2.2, U1.27 (GPIO21)
/GP22: J1.5, U1.29 (GPIO22)
/GP26: J1.3, U1.31 (GPIO26_ADC0)
/GP27: J1.1, U1.32 (GPIO27_ADC1)
/GP28: J1.2, U1.34 (GPIO28_ADC2)
/RUN: SW1.1, U1.30 (RUN)
/SWCLK: J2.1, R5.1
/SWDIO: J2.3, R6.1
/UART0_RX: J3.3, R4.1
/UART0_TX: J3.1, R3.1
/VBUS: U1.40 (VBUS)
/VSYS: J1.4, J1.6, U1.39 (VSYS)
GND: C1.2, J1.12, J1.14, J1.16, J2.2, J3.2, LCD1.2 (GND), SW1.2, SW1.3, SW1.4, SW2.2, SW2.3, SW2.4, U1.3 (GND), U1.8 (GND), U1.13 (GND), U1.18 (GND), U1.23 (GND), U1.28 (GND), U1.33 (AGND), U1.38 (GND), U1.42 (GND)
unnamed: LCD1.5 (DC/RS), R8.2
unnamed: LCD1.9 (MISO), R11.2
unnamed: LCD1.6 (MOSI), R9.2
unnamed: LCD1.7 (SCK), R10.2
unnamed: LCD1.10 (T_CLK), R12.2
unnamed: LCD1.11 (T_CS), R13.2
unnamed: LCD1.12 (T_DIN), R14.2
unnamed: LCD1.13 (T_DO), R15.2
unnamed: LCD1.3 (~CS), R7.2
unnamed: R5.2, U1.41 (SWCLK)
unnamed: R6.2, U1.43 (SWDIO)
unnamed: SW2.1, U1.44 (TP6)

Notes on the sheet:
Si4735 SCK
TP MISO
Si4735 RESET
Si4735 SDA
Si4735 RCLK
TP CS
I2S LRCLK
LCD LED
MUTE
I2S BITCLK
LCD DC
LCD CS
LCD RESET
TP MOSI
LCD MISO
LCD MOSI
LCD SCK
TP SCK

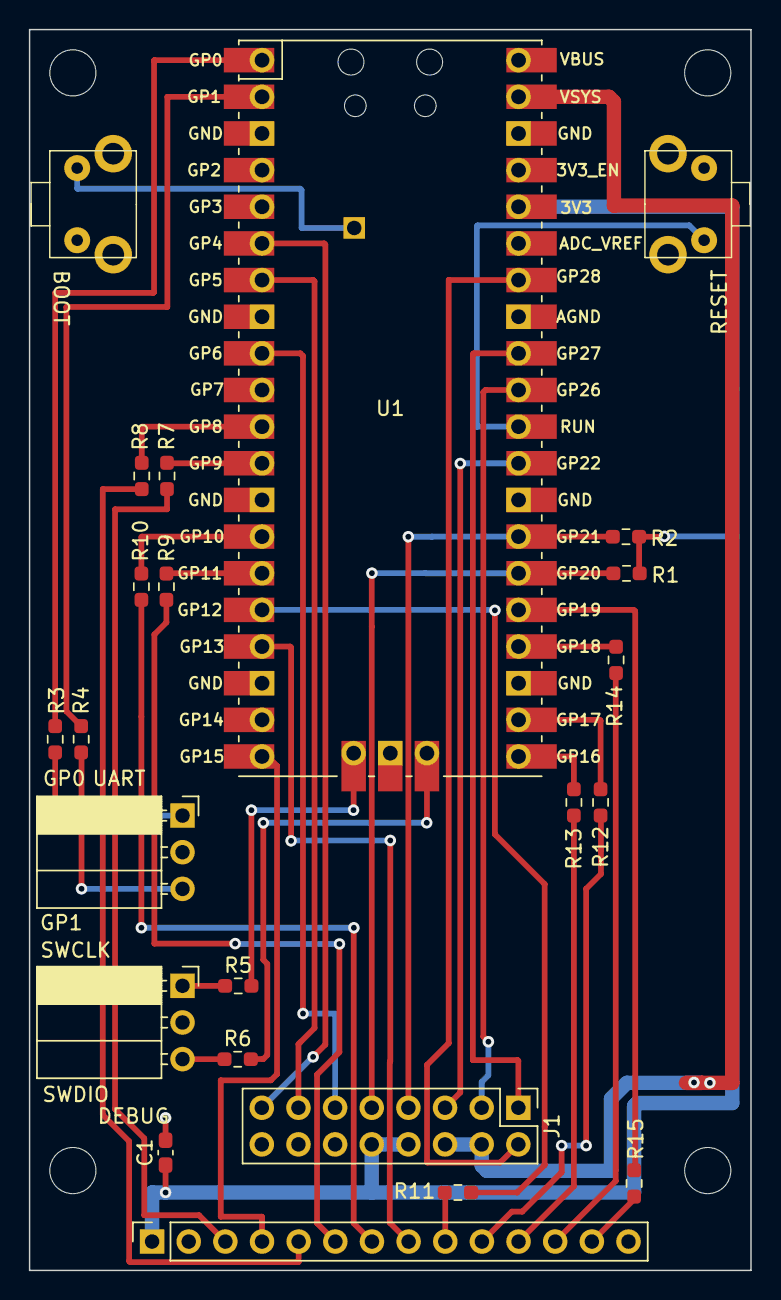
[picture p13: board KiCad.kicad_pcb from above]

Board: 2 copper layers, 50.0 x 86.0 mm, 27 parts (0 on the bottom side), 42 nets.

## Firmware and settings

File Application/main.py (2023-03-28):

import machine
import rp2_dma
import sys
import time
import json
import lvgl as lv
import MSP2807_ILI9341
import MSP2807_XPT2046

mutesp = machine.Pin(26, machine.Pin.OUT)
mutehp = machine.Pin(27, machine.Pin.OUT)
mutesp.value(1)
mutehp.value(1)

def printBytes(bs):
    for i in range(len(bs)):
        printHex(bs[i])
    print()

def printHex(h):
    tbl = "0123456789ABCDEF"
    r = h % 16
    x = int(h / 16)
    print(tbl[x], end="")
    print(tbl[r], end="")
    print(" ", end="")

# Generate 48k I2S clock
# uncomment I2S OUTPUT
# @rp2.asm_pio(
#     sideset_init=(rp2.PIO.OUT_HIGH, rp2.PIO.OUT_HIGH)
# )
# def gen48k():
#     set(x, 30)       .side(0b00) [1]
#     nop()            .side(0b01) [1]
#     label("L01")
#     nop()            .side(0b00) [1]
#     jmp(x_dec, "L01").side(0b01) [1]
#     set(x, 30)       .side(0b10) [1]
#     nop()            .side(0b11) [1]
#     label("R01")
#     nop()            .side(0b10) [1]
#     jmp(x_dec, "R01").side(0b11) [1]
# 
# sm0 = rp2.StateMachine(
#     0,
#     gen48k,
#     freq=12_288_000,
#     sideset_base=machine.Pin(4)
# )
# sm0.active(1)

@rp2.asm_pio(
    set_init=(rp2.PIO.OUT_HIGH)
)
def gen32k():
    set(pins, 1) [4]
    set(pins, 0) [4]

sm1 = rp2.StateMachine(
    1,
    gen32k,
    freq=327_680,
    set_base=machine.Pin(6)
)
sm1.active(1)

class Si4735(object):
    mode = [
        ['FM',  76000,108000, 10],
        ['AM',    531,  1602,  9],
        ['LW',    153,   279,  9],
        ['120m', 2300,  2495,  5],
        ['90m',  3200,  3400,  5],
        ['75m',  3900,  4000,  5],
        ['60m',  4750,  5060,  5],
        ['49m',  5730,  6295,  5],
        ['41m',  7100,  7600,  5],
        ['31m',  9250,  9900,  5],
        ['25m', 11600, 12100,  5],
        ['22m', 13570, 13870,  5],
        ['19m', 15030, 15800,  5],
        ['16m', 17480, 17900,  5],
        ['15m', 18900, 19020,  5],
        ['13m', 21450, 21750,  5],
        ['11m', 25670, 26100,  5],
        ['SW',   2300, 26100,  5]
    ]

    def __init__(self, i2c, reset = 22):
        self.addr=0x63
        self.i2c=i2c
        self.reset = machine.Pin(reset, machine.Pin.OUT)
        self.hard_reset()
        self.modeIdx = -1

    def getModeIdx(self, khz):
        for i in range(len(self.mode)):
            if khz >= self.mode[i][1] and khz <= self.mode[i][2]:
                return i
        return -1

    def hard_reset(self):
        if self.reset:
            for val in (1, 0, 1):
                self.reset.value(val)
                time.sleep(0.1)
            time.sleep(0.1)

    def setProperty(self, buf=None):
        self.buf = bytes([0x12, 0x00]) + buf
        self.i2c.writeto(self.addr, self.buf)
        self.waitCTS()
        
    def getProperty(self, buf=None):
        self.i2c.writeto(self.addr, bytes([0x13, 0x00]) + buf)
        self.waitCTS()
        self.resp = self.i2c.readfrom(self.addr, 4)
        print("getProperty: ",end="")
        printBytes(self.resp)

    def FMPOWER_UP(self):
        self.i2c.writeto(self.addr, bytes([0x01, 0x00, 0x05]))  # analog Out
#         self.i2c.writeto(self.addr, bytes([0x01, 0x00, 0xB0]))   # I2S
        self.waitCTS()
        time.sleep(0.5)
        self.setProperty(bytes([0xFF, 0x00, 0x00, 0x00]))          # Turn off Debug Mode
#         self.setProperty(bytes([0x01, 0x04, 0xBB, 0x80]))        # I2s sample rate

    def FM_SEEK_BAND_BOTTOM(self, freq):
        self.setProperty(bytes([0x14, 0x00]) + freq.to_bytes(2, 'big'))

    def FM_SEEK_BAND_TOP(self, freq):
        self.setProperty(bytes([0x14, 0x01]) + freq.to_bytes(2, 'big'))

    def FM_SEEK_FREQ_SPACING(self, step):
        self.setProperty(bytes([0x14, 0x02, 0x00]) + step.to_bytes(1, 'big')) # 5(50kHz), 10(100kHz), 20(200kHz)

    def AMPOWER_UP(self):
        self.i2c.writeto(self.addr, bytes([0x01, 0x01, 0x05])) # analog out
#         self.i2c.writeto(self.addr, bytes([0x01, 0x01, 0xB0]))  # I2S
        self.waitCTS()
        time.sleep(0.5)
        self.setProperty(bytes([0xFF, 0x00, 0x00, 0x00]))         # Turn off Debug Mode
#         self.setProperty(bytes([0x01, 0x04, 0xBB, 0x80]))       # I2S sample rate

    def AM_SEEK_BAND_BOTTOM(self, freq):
        self.setProperty(bytes([0x34, 0x00]) + freq.to_bytes(2, 'big'))

    def AM_SEEK_BAND_TOP(self, freq):
        self.setProperty(bytes([0x34, 0x01]) + freq.to_bytes(2, 'big'))

    def AM_SEEK_FREQ_SPACING(self, step):
        self.setProperty(bytes([0x34, 0x02, 0x00]) + step.to_bytes(1, 'big')) # 1 (1kHz), 5 (5kHz), 9 (9kHz), and 10 (10kHz).

    def POWER_DOWN(self):
        self.i2c.writeto(self.addr, bytes([0x11]))
        self.waitCTS()
        time.sleep(1)
    
    def setFMDeEmphasis(self):
        self.setProperty(bytes([0x11, 0x00, 0x00, 0x01]))  # 01 = 50 μs. Used in Europe, Australia, Japan

    def FM_TUNE_FREQ(self, freq, fast=None):
        self.freq=freq
        self.fast=fast
        param = bytes([0x20, 0x00]) if fast == None else bytes([0x20, 0x01])
        self.i2c.writeto(self.addr, param + freq.to_bytes(2, 'big'))
        self.waitCTS()

    def AM_TUNE_FREQ(self, freq, fast=None):
        self.freq=freq
        self.fast=fast
        param = bytes([0x40, 0x00]) if fast == None else bytes([0x40, 0x01])
        self.i2c.writeto(self.addr, param + freq.to_bytes(2, 'big'))
        self.waitCTS()

    def FM_SEEK_START(self, seekDir):
        arg1 = 0b00001100 if seekDir == 1 else 0b00000100
        self.i2c.writeto(self.addr, bytes([0x21, arg1]))
        self.waitCTS()

    def AM_SEEK_START(self, seekDir):
        arg1 = 0b00001100 if seekDir == 1 else 0b00000100
        self.i2c.writeto(self.addr, bytes([0x41, arg1]))
        self.waitCTS()

    def FM_TUNE_STATUS(self):
        self.i2c.writeto(self.addr, bytes([0x22, 0x00]))
        self.waitCTS()
        resp = self.i2c.readfrom(self.addr, 7)
        self.freq = resp[2] * 256
        self.freq = self.freq + resp[3]
        self.rssi = resp[4]
        self.snr  = resp[5]
        self.valid = resp[1] & 0b0000_0001

    def AM_TUNE_STATUS(self):
        self.i2c.writeto(self.addr, bytes([0x42, 0x00]))
        self.waitCTS()
        resp = self.i2c.readfrom(self.addr, 7)
        self.freq = resp[2] * 256
        self.freq = self.freq + resp[3]
        self.rssi = resp[4]
        self.snr  = resp[5]
        self.valid = resp[1] & 0b0000_0001

    def FM_RSQ_STATUS(self):
        self.i2c.writeto(self.addr, bytes([0x23, 0x00]))
        self.waitCTS()
        resp = self.i2c.readfrom(self.addr, 7)
        self.rssi = resp[4]
        self.snr  = resp[5]
        self.stblend = resp[3] & 0x7f
        self.valid = resp[2] & 0b0000_0001

    def AM_RSQ_STATUS(self):
        self.i2c.writeto(self.addr, bytes([0x43, 0x00]))
        self.waitCTS()
        resp = self.i2c.readfrom(self.addr, 7)
        self.rssi = resp[4]
        self.snr  = resp[5]
        self.stblend = resp[3] & 0x7f
        self.valid = resp[2] & 0b0000_0001

    def setVolume(self, vol):
        self.vol = vol
        if self.vol > 63:
            self.vol = 63
        self.setProperty(bytes([0x40, 0x00]) + self.vol.to_bytes(2, 'big'))

    def unmute(self):
        self.setProperty(bytes([0x40, 0x01, 0x00, 0x00]))

    def mute(self):
        self.setProperty(bytes([0x40, 0x01, 0x00, 0x03]))

    def waitCTS(self):
        while True:
            cts = self.i2c.readfrom(self.addr, 1)
            if cts >= b'0x80': break

    def getFmFreqStr(self):
        f1 = str(self.freq / 100)
        f1last = len(f1)
        if f1last > 6:
            f2 = f1[f1last - 1]
            f3 = f1.rstrip(f2)
            f4 = f3.rstrip('0')
        else:
            f4 = f1.rstrip('0')
        if f4[-1] == '.': f4 = f4 + "0"
        f4 = f4 + "MHz"
        return f4

    def getAmFreqStr(self):
        f1 = str(self.freq)
        f1 = f1 + "kHz"
        return f1

i2c = machine.I2C(0, scl=machine.Pin(21), sda=machine.Pin(20), freq=50_000)
spi=machine.SPI(
    1,
    baudrate=43_000_000,
    polarity=0,
    phase=0,
    sck=machine.Pin(10,machine.Pin.OUT),
    mosi=machine.Pin(11,machine.Pin.OUT),
    miso=machine.Pin(12,machine.Pin.IN)
)        

dma0=rp2_dma.DMA(1)

disp = MSP2807_ILI9341.ILI9341(
    rot=MSP2807_ILI9341.PORTRAIT,
    res=(240,320),
    spi=spi,
    cs=9,
    dc=8,
    bl=13,
    rst=15,
    doublebuffer=True,
    factor = 8,
    bgr=False,
    rp2_dma=dma0
)
disp.set_backlight(100)

spi2 = machine.SoftSPI(
    baudrate=1_000_000,
    polarity=0,
    phase=0,
    sck =machine.Pin(17,machine.Pin.OUT),
    mosi=machine.Pin(18,machine.Pin.OUT),
    miso=machine.Pin(19,machine.Pin.IN)
)
touch = MSP2807_XPT2046.Xpt2046(spi=spi2,cs=16,rot=MSP2807_XPT2046.PORTRAIT)

tabview = lv.tabview(lv.scr_act(), lv.DIR.BOTTOM, 16)
tab1 = tabview.add_tab("MAIN")
tab2 = tabview.add_tab("Station")

def tab1_event(e):
    if btnStepDown.is_visible():
        btnStepDown.add_flag(lv.obj.FLAG.HIDDEN)
        btnStepUp.add_flag(lv.obj.FLAG.HIDDEN)
        kbd.clear_flag(lv.obj.FLAG.HIDDEN)
        st.contVisible(False)
    else:
        btnStepDown.clear_flag(lv.obj.FLAG.HIDDEN)
        btnStepUp.clear_flag(lv.obj.FLAG.HIDDEN)
        kbd.add_flag(lv.obj.FLAG.HIDDEN)
        st.contVisible(True)

tab1.add_event(tab1_event, lv.EVENT.LONG_PRESSED, None)

class freqStep(object):
    def __init__(self):
        self.col_dsc = [40, 40, 40, 40, lv.GRID_TEMPLATE_LAST]
        self.row_dsc = [18, 18, lv.GRID_TEMPLATE_LAST]
        self.step = [
            [1,"1k"], [5,"5k"], [9,"9k"], [10,"10k"],
            [50,"50k"], [100,"100k"], [500,"500k"], [1000,"1M"],
        ]
        self.stepIdx = 0
        self.lastFmIdx = 5
        self.lastAmIdx = 1
        self.createTable()

    def step_cb(self, event_struct):
        event = event_struct.code
        if event == lv.EVENT.CLICKED:
            if self.mode == 0:
                self.lastfmidx = self.stepIdx
            else:
                self.lastamidx = self.stepIdx
            targetLabel = event_struct.get_target_obj()
            self.stepIdx = targetLabel.get_index()
            self.changebg(self.stepIdx)

    def createTable(self):
        self.cont = lv.obj(tab1)
        self.cont.set_style_grid_column_dsc_array(self.col_dsc, 0)
        self.cont.set_style_grid_row_dsc_array(self.row_dsc, 0)
        self.cont.set_size(lv.pct(100), lv.pct(27))
        self.cont.set_style_bg_color( lv.color_hex(0xe0e0ff), lv.PART.MAIN | lv.STATE.DEFAULT )
        self.cont.align_to(tab1, lv.ALIGN.BOTTOM_MID, 0, -42)
        self.cont.set_layout(lv.LAYOUT_GRID.value)

        for i in range(len(self.step)):
            col = i % 4
            row = i // 4
            obj = lv.label(self.cont)
            obj.set_style_bg_color( lv.color_hex(0xffffff), lv.PART.MAIN | lv.STATE.DEFAULT )
            obj.set_style_bg_opa(255, lv.PART.MAIN| lv.STATE.DEFAULT )
            obj.set_style_text_font(lv.font_montserrat_12, 0)
            obj.set_style_text_align( lv.TEXT_ALIGN.CENTER, lv.PART.MAIN | lv.STATE.DEFAULT )
            obj.set_style_border_color( lv.color_hex(0xFF0000), lv.PART.MAIN | lv.STATE.DEFAULT )
            obj.set_style_border_width( 1, lv.PART.MAIN | lv.STATE.DEFAULT )
            obj.set_style_pad_left( 1, lv.PART.MAIN | lv.STATE.DEFAULT )
            obj.set_style_pad_right( 1, lv.PART.MAIN | lv.STATE.DEFAULT )
            obj.set_style_pad_top( 1, lv.PART.MAIN | lv.STATE.DEFAULT )
            obj.set_style_pad_bottom( 1, lv.PART.MAIN | lv.STATE.DEFAULT )
            obj.set_style_radius( 8, lv.PART.MAIN | lv.STATE.DEFAULT )
            obj.add_event(self.step_cb, lv.EVENT.ALL, None)
            obj.set_text(self.step[i][1])
            obj.set_grid_cell(lv.GRID_ALIGN.STRETCH, col, 1,
                              lv.GRID_ALIGN.STRETCH, row, 1)

    def getStep(self):
        if self.mode == 0:
            return int(self.step[self.stepIdx][0] / 10)
        elif self.mode == 1:
            return self.step[self.stepIdx][0]
        else:
            return 0

    def changebg(self, idx):
        if self.mode == 0:
            for i in (0,1,2,3):
                obj = self.cont.get_child(i)
                obj.set_style_bg_color( lv.color_hex(0xA0A0A0), lv.PART.MAIN | lv.STATE.DEFAULT )
            for i in (4,5,6,7):
                obj = self.cont.get_child(i)
                obj.set_style_bg_color( lv.color_hex(0xffffff), lv.PART.MAIN | lv.STATE.DEFAULT )
        elif self.mode == 1:
            for i in range(8):
                obj = self.cont.get_child(i)
                obj.set_style_bg_color( lv.color_hex(0xffffff), lv.PART.MAIN | lv.STATE.DEFAULT )
        obj = self.cont.get_child(idx)
        obj.set_style_bg_color( lv.color_hex(0xff8080), lv.PART.MAIN | lv.STATE.DEFAULT )
        self.stepIdx = idx
        if self.mode == 0:
            self.lastFmIdx = self.stepIdx
        elif self.mode == 1:
            self.lastAmIdx = self.stepIdx

    def changeFM(self):
        self.mode = 0
        for i in range(4):
            obj = self.cont.get_child(i)
            obj.clear_flag(lv.obj.FLAG.CLICKABLE)
        self.changebg(self.lastFmIdx)

    def changeAM(self):
        self.mode = 1
        for i in range(8):
            obj = self.cont.get_child(i)
            obj.add_flag(lv.obj.FLAG.CLICKABLE)
        self.changebg(self.lastAmIdx)

    def contVisible(self, visi=True):
        if visi == True:
            self.cont.clear_flag(lv.obj.FLAG.HIDDEN)
        else:
            self.cont.add_flag(lv.obj.FLAG.HIDDEN)


labelTitle = lv.label(tab1)
labelTitle.set_width(lv.pct(50))
labelTitle.set_text("Si4735 RADIO\nJP3SRS")
labelTitle.set_style_text_font(lv.font_GenJyuuGothic_Normal_16, 0)
labelTitle.set_style_text_align( lv.TEXT_ALIGN.RIGHT, lv.PART.MAIN | lv.STATE.DEFAULT )
#labelTitle.set_long_mode(lv.label.LONG.SCROLL_CIRCULAR)
labelTitle.align(lv.ALIGN.TOP_RIGHT, 0, 0)

kbd_map = ["7", "8", "9", "M", "\n",
          "4", "5", "6", "k", "\n",
          "1", "2", "3", "C", "\n",
          "0", ".", "<<" ,">>", None]

kbd_ctrl = [ 2, 2, 2, 2,
            2, 2, 2, 2,
            2, 2, 2, 2,
            2, 2, 2, 2 ]

saveFreq = ""
def kbd_valueChange(event_struct):
    btnm = lv.btnmatrix.__cast__(event_struct.get_target())
    btn = btnm.get_selected_btn()
    txt = btnm.get_btn_text(btn)
    global saveFreq
    if txt == "<<":
        kbdTextArea.del_char()
        kbdTextArea.del_char()
        if len(saveFreq) > 0: return
        if radio.modeIdx == 0:
            radio.FM_SEEK_START(0)
        elif radio.modeIdx > 0:
            radio.AM_SEEK_START(0)
        timer1.resume()
        return
    if txt == ">>":
        kbdTextArea.del_char()
        kbdTextArea.del_char()
        if len(saveFreq) > 0: return
        if radio.modeIdx == 0:
            radio.FM_SEEK_START(1)
        elif radio.modeIdx >0:
            radio.AM_SEEK_START(1)
        timer1.resume()
        return
    if txt == "C":
        a = kbdTextArea.get_text()
        if len(a) > 2 and a[-1] == 'C' and a[-2] == 'z':
            kbdTextArea.del_char()
            saveFreq = kbdTextArea.get_text()
            kbdTextArea.set_text("")
            timer1.pause()
        elif len(saveFreq) > 0:
            kbdTextArea.set_text(saveFreq)
            saveFreq = ""
            timer1.resume()
        return
    taText = kbdTextArea.get_text()
    if len(taText) > 3:
        if taText[-2] == "z":
            kbdTextArea.del_char()
            return
    if txt == ".":
        taText = kbdTextArea.get_text()
        dot = 0
        for i in taText:
            if i == ".":
                dot += 1
        if dot > 1:
            kbdTextArea.del_char()
            return
    if txt == "M" or txt == "k":
        saveFreq = ""
        kbdTextArea.add_text("Hz")
        radioTune(kbdTextArea.get_text())
        timer1.resume()

def btnStepDown_cb(event):
    timer1.pause()
    newFreq = radio.freq - st.getStep()
    if radio.modeIdx == 0:
        if (newFreq * 10) >= radio.mode[0][1] and (newFreq * 10) <= radio.mode[0][2]:
            radio.FM_TUNE_FREQ(newFreq, fast = True)
            kbdTextArea.set_text(radio.getFmFreqStr())
    else:
        if newFreq >= 149 and newFreq <= 23000:
            newMode = radio.getModeIdx(newFreq)
            if newMode != radio.modeIdx:
                modeBtnLabel.set_text(radio.mode[newMode][0])
                radio.modeIdx = newMode
            radio.AM_TUNE_FREQ(newFreq, fast = True)
            kbdTextArea.set_text(radio.getAmFreqStr())
    timer1.resume()

def btnStepUp_cb(event):
    timer1.pause()
    newFreq = radio.freq + st.getStep()
    if radio.modeIdx == 0:
        if newFreq * 10 >= radio.mode[0][1] and newFreq * 10 <= radio.mode[0][2]:
            radio.FM_TUNE_FREQ(newFreq, fast = True)
            kbdTextArea.set_text(radio.getFmFreqStr())
    else:
        if newFreq >= 149 and newFreq <= 23000:
            newMode = radio.getModeIdx(newFreq)
            if newMode != radio.modeIdx:
                modeBtnLabel.set_text(radio.mode[newMode][0])
                radio.modeIdx = newMode
            radio.AM_TUNE_FREQ(newFreq, fast = True)
            kbdTextArea.set_text(radio.getAmFreqStr())
    timer1.resume()

btnStepDown = lv.btn(tab1)
btnStepDown.add_event(btnStepDown_cb, lv.EVENT.CLICKED, None)
btnStepDown.add_event(btnStepDown_cb, lv.EVENT.LONG_PRESSED_REPEAT, None)
btnStepDown.set_width(lv.pct(40))
btnStepDown.align_to(tab1, lv.ALIGN.BOTTOM_MID, -50, -18)
btnStepDownLabel = lv.label(btnStepDown)
btnStepDownLabel.set_text("<<")
btnStepDownLabel.align_to(btnStepDown, lv.TEXT_ALIGN.CENTER, 0,0)

btnStepUp = lv.btn(tab1)
btnStepUp.add_event(btnStepUp_cb, lv.EVENT.CLICKED, None)
btnStepUp.add_event(btnStepUp_cb, lv.EVENT.LONG_PRESSED_REPEAT, None)
btnStepUp.set_width(lv.pct(40))
btnStepUp.align_to(tab1, lv.ALIGN.BOTTOM_MID, 50, -18)
btnStepUpLabel = lv.label(btnStepUp)
btnStepUpLabel.set_text(">>")
btnStepUpLabel.align_to(btnStepUp, lv.TEXT_ALIGN.CENTER, 0,0)

kbd = lv.keyboard(tab1)
kbd.set_y(0)
kbd.set_map(lv.keyboard.MODE.USER_1, kbd_map, kbd_ctrl)
kbd.set_mode(lv.keyboard.MODE.USER_1)
kbd.add_event(kbd_valueChange, lv.EVENT.VALUE_CHANGED, None)
kbd.set_width(lv.pct(100))
kbd.set_height(lv.pct(42))
kbd.align_to(tab1, lv.ALIGN.BOTTOM_MID, 0, 0)
kbd.add_flag(lv.obj.FLAG.HIDDEN)

kbdTextArea = lv.textarea(tab1)
kbdTextArea.set_style_text_font(lv.font_GenJyuuGothic_Monospace_Medium_34, 0)
kbdTextArea.set_width(lv.pct(100))
kbdTextArea.set_height(lv.pct(18))
kbdTextArea.align_to(kbd, lv.ALIGN.TOP_MID, 0, -80)
kbdTextArea.add_state(lv.STATE.FOCUSED)
kbdTextArea.set_scrollbar_mode(lv.SCROLLBAR_MODE.OFF)
kbdTextArea.clear_flag(lv.obj.FLAG.CLICKABLE)
kbdTextArea.clear_flag(lv.obj.FLAG.SCROLLABLE)
kbdTextArea.set_style_text_align( lv.TEXT_ALIGN.CENTER, lv.PART.MAIN | lv.STATE.DEFAULT)
kbdTextArea.clear_state(lv.STATE.FOCUSED)
kbdTextArea.set_one_line(True)
kbd.set_textarea(kbdTextArea)

def volumeSlider_event_cb(event):
    slider = event.get_target_obj()
    volumeSliderLabel.set_text("Vol {:d}".format(slider.get_value()))
    volumeSliderLabel.align_to(slider, lv.ALIGN.LEFT_MID, -60, 0)
    radio.setVolume(slider.get_value())

volumeSlider = lv.slider(tab1)
volumeSlider.set_width(lv.pct(60))
volumeSlider.set_height(lv.pct(5))
volumeSlider.align_to(kbdTextArea, lv.ALIGN.TOP_RIGHT, 0, -30)
volumeSlider.set_range(0,63)
volumeSlider.add_event(volumeSlider_event_cb, lv.EVENT.VALUE_CHANGED, None)

volumeSliderLabel = lv.label(tab1)
volumeSliderLabel.set_text("Vol 0")
volumeSliderLabel.align_to(volumeSlider, lv.ALIGN.LEFT_MID, -60, 0)

style_indic = lv.style_t()
style_indic.init()
style_indic.set_bg_opa(lv.OPA.COVER)
style_indic.set_bg_color(lv.color_hex(0x800000))
style_indic.set_bg_grad_color(lv.color_hex(0xff0000))
style_indic.set_bg_grad_dir(lv.GRAD_DIR.HOR)
smeterBar = lv.bar(tab1)
smeterBar.add_style(style_indic, lv.PART.INDICATOR)
smeterBar.set_size(100, 10)
smeterBar.set_range(0, 160)
smeterBar.align_to(kbdTextArea, lv.ALIGN.BOTTOM_MID, 50, 25)
smeterBar.set_value(0, lv.ANIM.OFF)

labelSignal = lv.label(tab1)
labelSignal.set_text("000dBu")
labelSignal.set_style_text_font(lv.font_montserrat_12, 0)
labelSignal.align_to(smeterBar, lv.ALIGN.LEFT_MID, -54, 0)

labelSnr = lv.label(tab1)
labelSnr.set_text("000dB")
labelSnr.set_style_text_font(lv.font_montserrat_12, 0)
labelSnr.align_to(labelSignal, lv.ALIGN.LEFT_MID, -40, 0)

modeBtnLabel = lv.label(tab1)
modeBtnLabel.set_text("")
modeBtnLabel.set_style_text_font(lv.font_GenJyuuGothic_Monospace_Medium_34, 0)
modeBtnLabel.set_style_text_color( lv.color_hex(0xffffff), lv.PART.MAIN | lv.STATE.DEFAULT )
modeBtnLabel.set_style_text_opa(255, lv.PART.MAIN| lv.STATE.DEFAULT )
modeBtnLabel.set_style_text_align( lv.TEXT_ALIGN.CENTER, lv.PART.MAIN | lv.STATE.DEFAULT )
modeBtnLabel.set_width(lv.pct(40))	# 1
modeBtnLabel.set_height(36)   # 1
modeBtnLabel.set_align(lv.ALIGN.TOP_LEFT)
modeBtnLabel.set_style_pad_left( 2, lv.PART.MAIN | lv.STATE.DEFAULT )
modeBtnLabel.set_style_pad_right( 2, lv.PART.MAIN | lv.STATE.DEFAULT )
modeBtnLabel.set_style_pad_top( 2, lv.PART.MAIN | lv.STATE.DEFAULT )
modeBtnLabel.set_style_pad_bottom( 2, lv.PART.MAIN | lv.STATE.DEFAULT )
modeBtnLabel.set_style_bg_color(lv.color_hex(0xa0a0a0), lv.PART.MAIN | lv.STATE.DEFAULT)
modeBtnLabel.set_style_bg_opa(255, lv.PART.MAIN | lv.STATE.DEFAULT)
modeBtnLabel.set_style_radius( 8, lv.PART.MAIN | lv.STATE.DEFAULT )

labelSTBLEND = lv.label(tab1)
labelSTBLEND.set_text("000%")
labelSTBLEND.set_style_text_font(lv.font_montserrat_12, 0)
labelSTBLEND.set_style_bg_color(lv.color_make(255, 255, 255), lv.PART.MAIN | lv.STATE.DEFAULT)
labelSTBLEND.set_style_bg_opa(255, lv.PART.MAIN | lv.STATE.DEFAULT)
labelSTBLEND.set_style_pad_left( 2, lv.PART.MAIN | lv.STATE.DEFAULT )
labelSTBLEND.set_style_pad_right( 2, lv.PART.MAIN | lv.STATE.DEFAULT )
labelSTBLEND.set_style_pad_top( 2, lv.PART.MAIN | lv.STATE.DEFAULT )
labelSTBLEND.set_style_pad_bottom( 2, lv.PART.MAIN | lv.STATE.DEFAULT )
labelSTBLEND.align_to(modeBtnLabel, lv.ALIGN.BOTTOM_LEFT, 0, 24)
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

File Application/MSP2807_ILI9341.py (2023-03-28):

'''
  @ 2022 Masahiro Kusunoki masahiro.kusunoki@gmail.com
  This driver is based on lv_binding micropython generic driver named st77xx.py
  written by eudoxos and rewritten by Masahiro Kusunoki for ili9341 SKU:MSP2807.
  https://github.com/lvgl/lv_binding_micropython/blob/master/driver/generic/st77xx.py

  Initialization was based on the Adafruit.
  https://github.com/adafruit/Adafruit_ILI9341/blob/master/Adafruit_ILI9341.h
  https://github.com/adafruit/Adafruit_ILI9341/blob/master/Adafruit_ILI9341.cpp

--------------------------------------------------------------------------------
https://github.com/adafruit/Adafruit_ILI9341 readme.md
Adafruit ILI9341 Arduino Library Build StatusDocumentation

  This is a library for the Adafruit ILI9341 display products
  This library works with the Adafruit 2.8" Touch Shield V2 (SPI)

    http://www.adafruit.com/products/1651

  Adafruit 2.4" TFT LCD with Touchscreen Breakout w/MicroSD Socket - ILI9341

    https://www.adafruit.com/product/2478

  2.8" TFT LCD with Touchscreen Breakout Board w/MicroSD Socket - ILI9341

    https://www.adafruit.com/product/1770

  2.2" 18-bit color TFT LCD display with microSD card breakout - ILI9340

    https://www.adafruit.com/product/1480

  TFT FeatherWing - 2.4" 320x240 Touchscreen For All Feathers

    https://www.adafruit.com/product/3315

Check out the links above for our tutorials and wiring diagrams. These displays use SPI to communicate,
4 or 5 pins are required to interface (RST is optional).

BMP image-loading examples have been moved to the Adafruit_ImageReader library:
https://github.com/adafruit/Adafruit_ImageReader

Adafruit invests time and resources providing this open source code, please support Adafruit and
open-source hardware by purchasing products from Adafruit!

Written by Limor Fried/Ladyada for Adafruit Industries.
MIT license, all text above must be included in any redistribution

To download. click the DOWNLOADS button in the top right corner, rename the uncompressed folder Adafruit_ILI9341.
Check that the Adafruit_ILI9341 folder contains Adafruit_ILI9341.cpp and Adafruit_ILI9341.

Place the Adafruit_ILI9341 library folder your arduinosketchfolder/libraries/ folder.
You may need to create the libraries subfolder if its your first library. Restart the IDE

Also requires the Adafruit_GFX library for Arduino.
--------------------------------------------------------------------------------
MIT License

Copyright (c) [2022] [Masahiro Kusunoki]

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
'''
import time
import machine
import struct
import uctypes
from micropython import const

ILI9341_SLPOUT = const(0x11)
ILI9341_GAMMASET = const(0x26)
ILI9341_DISPON = const(0x29)
ILI9341_CASET  = const(0x2A)
ILI9341_RASET  = const(0x2B)
ILI9341_RAMWR  = const(0x2C)
ILI9341_MADCTL = const(0x36)
ILI9341_VSCRSADD = const(0x37)
ILI9341_PIXFMT  = const(0x3A)
ILI9341_FRMCTR1 = const(0xB1)
ILI9341_DFUNCTR = const(0xB6)
ILI9341_PWCTR1  = const(0xC0)
ILI9341_PWCTR2  = const(0xC1)
ILI9341_VMCTR1  = const(0xC5)
ILI9341_VMCTR2  = const(0xC7)
ILI9341_GMCTRP1 = const(0xE0)
ILI9341_GMCTRN1 = const(0xE1)

MADCTL_MX = const(0x40)
MADCTL_MY = const(0x80)
MADCTL_MV = const(0x20)
MADCTL_ML = const(0x10)
MADCTL_BGR = const(0x08)
MADCTL_MH = const(0x04)

PORTRAIT = const(0)
LANDSCAPE = const(1)
INV_PORTRAIT = const(2)
INV_LANDSCAPE = const(3)

class ILIxxxx_hw(object):
    def __init__(self, *, cs = 9, dc = 8, spi, res=(240,320), bl = 13, rst = 15, rot = PORTRAIT, bgr = False, rp2_dma = None):
        '''
        This is an abstract low-level driver the ST77xx controllers, not to be instantiated directly.
        Derived classes implement chip-specific bits. THe following parameters are recognized:

        * *cs*: chip select pin (= slave select, SS)
        * *dc*: data/command pin
        * *bl*: backlight PWM pin (optional)
        * *model*: display model, to account for variations in products
        * *rst*: optional reset pin
        * *res*: resolution tuple; (width,height) with zero rotation
        * *rot*: display orientation (0: portrait, 1: landscape, 2: inverted protrait, 3: inverted landscape); the constants PORTRAIT, LANDSCAPE, INV_POTRAIT, INV_LANDSCAPE may be used.
        * *bgr*: color order if BGR (not RGB)

        Subclass constructors (implementing concrete chip) set in addition the following, not to be used directly:

        * *suppModel*: models supported by the hardware driver
        * *suppRes*: resolutions supported by the hardware driver, as list of (width,height) tuples
        '''
        self.buf1 = bytearray(1)
        self.buf2 = bytearray(2)
        self.buf4 = bytearray(4)

        self.cs = machine.Pin(cs, machine.Pin.OUT)
        self.dc = machine.Pin(dc, machine.Pin.OUT)
        self.rst = machine.Pin(rst, machine.Pin.OUT)
        self.bl = bl
        if isinstance(self.bl, int):
            self.bl = machine.PWM(machine.Pin(self.bl, machine.Pin.OUT))
        elif isinstance(self.bl,machine.Pin):
            self.bl = machine.PWM(self.bl)
        assert isinstance(self.bl,(machine.PWM, type(None)))

        self.set_backlight(10) # set some backlight
        self.rot = rot
        self.width, self.height = (0,0) # this is set later in hard_reset->config->apply_rotation
        self.res = res
        self.bgr = bgr
        self.spi = spi
        self.rp2_dma = rp2_dma
        self.hard_reset()

    def off(self):
        self.set_backlight(0)

    def hard_reset(self):
        if self.rst:
            for v in (1,0,1):
                self.rst.value(v)
                time.sleep(.2)
            time.sleep(.2)
        self.config()

    def config(self):
        self.config_hw() # defined in child classes
        self.apply_rotation(self.rot)

    def set_backlight(self,percent):
        if self.bl is None:
            return
        self.bl.duty_u16(percent*655)

    def set_window(self, x, y, w, h):
        struct.pack_into('>hh', self.buf4, 0, x, x + w - 1)
        self.write_register(ILI9341_CASET, self.buf4)
        struct.pack_into('>hh', self.buf4, 0, y, y + h - 1)
        self.write_register(ILI9341_RASET, self.buf4)

    def apply_rotation(self, rot):
        self.rot = rot
        if self.rot == 0:
            r = MADCTL_MX
            self.width  = self.res[0]
            self.height = self.res[1]
        elif self.rot == 1:
            r = MADCTL_MV
            self.width  = self.res[1]
            self.height = self.res[0]
        elif self.rot == 2:
            r = MADCTL_MY
            self.width  = self.res[0]
            self.height = self.res[1]
        elif self.rot == 3:
            r = (MADCTL_MX | MADCTL_MY | MADCTL_MV)
            self.width  = self.res[1]
            self.height = self.res[0]
        
        if self.bgr:
            self.write_register(ILI9341_MADCTL, bytes([r]))
        else:
            self.write_register(ILI9341_MADCTL, bytes([r | MADCTL_BGR]))
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

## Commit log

2023-03-28 add Materials
2023-05-02 update schematic and add KiCad Files
    [KiCad-B_Cu.gbr, KiCad-B_Mask.gbr, KiCad-B_Paste.gbr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]
2023-05-05 add PartsList.xlsx
    [PartsList.xlsx]
2023-05-05 modify PartList.xlsx
    [PartsList.xlsx]
2023-05-07 modify PartList
    [PartsList.xlsx]
2023-06-21 change R1, R2, R3 100ohm
    [KiCad-Si4735.kicad_sch]
2023-06-21 update R1, R2, R3 to 100ohm
    [PartsList.xlsx]
